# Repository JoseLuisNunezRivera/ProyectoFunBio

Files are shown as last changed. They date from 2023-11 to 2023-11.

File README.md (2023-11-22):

# Proyecto Fundamentos de Biodiseño: BIONOVA
**<p align="center">
¡Bienvenidos al repositorio del grupo 10 de Fundamentos de Biodiseño!**
</p>

# Conoce a nuestro equipo

<p align="center"> 
 
| Cargo | Apellidos y nombres | Imagen | GitHub |
|---|---| - | - |
| Coordinadora General | Micaela de Fátima Tassara Camarena |  | https://github.com/MDFTC |
| Coordinador de Modelado 3D | Jose Luis Jesús Nuñez Rivera | | https://github.com/JoseLuisNunezRivera | https://github.com/JoseLuisNunezRivera |
| Coordinador de Electrónica | Edgar Antonio Aguilar Ocas| | https://github.com/EdgarAguilar1 |
| Coordinadora de Programación | Andree Pascale Merino Contreras | | https://github.com/PascaleMerino |
| Coordinadora de Impresión 3D | Valeria Alejandra Leonardo Castillón | | https://github.com/ValeriaLeonardo |

</p>

# ¿A qué nos referimos con Open Science Hardware?
El Hardware es una parte esencial de procesos experimentales y los avances en la instrumentación han sido clave para revoluciones científicas. Sin embargo, la actual cadena de suministros de estos hardware científicos limita el acceso e impide la creatividad y personalización. El Open Science Hardware aborda esta problemática facilitando un espacio para compartir, diseñar y fabricar de manera abierta y accesible herramientas, dispositivos y equipos usados en investigaciones científicas y experimentos. Con esto se busca incrementar la transparencia, colaboración y accesibilidad en la comunidad científica, permitiendo que todo esto esté disponible gratuitamente a cualquiera para reproducir, modificar y compartir. [14]

# I. Analisis del caso 
- "Tema": Open Science Hardware para Salud y Laboratorio
- "Problemática": Aumento de quemaduras de segundo grado en menores de edad del país
 
### Contexto social
- Las quemaduras representan un desafío de salud pública a nivel global. No solo por la frecuencia y facilidad con la que ocurren, sino que, en función de su gravedad, pueden generar discapacidades e incluso la muerte. Según la OMS, a nivel mundial, se estima que alrededor de 180,000 muertes ocurren anualmente debido a quemaduras. En países con desarrollo medio y bajo, las quemaduras ocupan el tercer lugar como causa de muerte accidental. [1]
- En el Perú, “entre enero y febrero del 2023, el Instituto Nacional de Salud del Niño San Borja, recibió a 75 niños con quemaduras graves, cifra que se ha incrementado en 60% en relación al mismo periodo del 2022 que atendió a 47 menores de Lima y de las diversas regiones del país” [10].
- La recuperación de una persona quemada suele llevar semanas o incluso meses, durante los cuales experimenta dolor y sufrimiento tanto físico como emocional. El tratamiento y cuidado implica costos significativos, lo que genera tanto carga para el Estado como para la familia del afectado.(Martín y Piris, 2014). La morbilidad y mortalidad aumentan por la presencia de infección y por las heridas profundas que se presentan por la pérdida de la humedad de los tejidos expuestos por la quemadura. [2]
- Por otro lado, según los diagnósticos consignados en la base de datos de HIS, se puede identificar que las localizaciones más frecuentes de quemaduras son los extremos distales de los miembros (muñecas, manos, tobillos y pies), seguida de los miembros inferiores, cabeza - cuello. [3]

### Contexto económico
Uno de los tratamientos para quemaduras de segundo o tercer grado son los injertos de piel; sin embargo, este procedimiento médico es complejo puesto que se extrae piel sana para poder ser injertada en la zona quemada. Esto requiere un equipo especializado y recursos médicos no precarios, lo que significa un costo adicional. 
Según el Instituto Nacional de Salud del Niño, en la siguiente tabla se muestran los costos que un paciente puede asumir. 
**<p align="center"> **

Los costos pueden variar mucho según la región, el sistema de salud, el tipo de tratamiento requerido y otros factores.
### Definición del problema: 
Las quemaduras son lesiones producidas en tejido vivo, debido a la acción de agentes químicos o físicos, que provocan alteraciones que van desde un simple eritema transitorio hasta la destrucción total de las estructuras(4). 
La falta de tecnología de bioimpresión en Perú para el tratamiento de heridas por quemaduras representa una problemática grave en la atención médica. A medida que las quemaduras continúan siendo un problema de salud significativo en el país, la ausencia de esta tecnología avanzada limita las opciones de tratamiento efectivas y la posibilidad de una recuperación más rápida y completa para los pacientes. Esto se traduce en un aumento en la morbilidad y la carga económica en el sistema de salud peruano, así como en la calidad de vida disminuida para las personas afectadas por quemaduras. La falta de acceso a la bioimpresión también restringe la capacidad de la comunidad médica peruana para llevar a cabo investigaciones y avances en el campo de la regeneración de tejidos y la medicina regenerativa, lo que podría tener un impacto duradero en la atención médica en el país.
**<p align="center"> **

# II. Estado del arte 

## Productos comerciales
| Nombre | Características | Imágenes |
| --- | --- | --- |
| Biopen | El sistema Biopen incluye un sistema de extrusión motorizado, un cartucho de biotinta, una boquilla y una unidad de fotocurado. Con su unidad de luz visible reemplazable, permite reticular hidrogeles con diferentes fotoiniciadores. Con su sistema de extrusión ajustable, puede realizar bioimpresiones compatibles con las células y permite que el hidrogel cargado de células se imprima a la velocidad deseada en el cartucho. Fuente de fotocurado: LED de luz visible. Peso: 700 g. Velocidad de extrusión: 5 - 35 mm/min | WhatsApp Image 2023-09-12 at 23 39 20|
| AxceldaPen | Impresión de células óseas para tratar el desgaste de rodilla y daño al cartílago. Su bio tinta es a base de las propias células del paciente que son cultivadas previas a su cirugía, este proceso permite al cirujano medir el tamaño del cartílago necesario para cada paciente. | WhatsApp Image 2023-09-12 at 23 40 32 |
| iFixPen® | El iFixPen es un dispositivo de mano que entrega una estructura impresa en 3D directamente sobre defectos corneales. Entrega una estructura impresa en 3D directamente sobre defectos corneales. La tinta iFixInk, pendiente de patente, crea una estructura completamente transparente y biodegradable para sellar la herida, prevenir la infiltración de patógenos, aliviar el dolor y acelerar la curación. | WhatsApp Image 2023-09-12 at 23 41 24 |

## Patentes de invención y/o utilidad
### 1. CN110769771B: ROBOT IMPRESORA BIOLÓGICA TRIDIMENSIONAL. [15]
- Un sistema mínimamente invasivo que utiliza un robot quirúrgico como impresora tridimensional para fabricar tejido biológico en un sujeto. La planificación preoperatoria se utiliza para instruir y controlar el movimiento del robot y la extrusión robótica de biotinta. El movimiento del robot se coordina con la extrusión de tinta para formar capas del espesor y tamaño deseados, y el uso de diferentes tipos de tinta permite colocar el elemento compuesto. Dichos sistemas tienen un mecanismo de expulsión de biotinta de pequeño diámetro, generalmente en forma de cánula impulsada por un pistón, que permite el acceso a áreas con espacio limitado (como las articulaciones). El control robótico está programado para realizar un movimiento angular alrededor de un punto de pivote en un punto de inserción en el sujeto. La biotinta se puede almacenar en una capa predeterminada en la cánula para permitir la dispensación secuencial desde una cánula. Patente presentada en 2018, China.
La patente habla de un mecanismo de expulsión de biotinta de pequeño diámetro, en forma de cánula impulsada por un pistón, que utiliza un robot quirúrgico mientras que el prototipo pensado en el proyecto usa un “lápiz de impresión desmontable.” Estos son tipos de dispositivos de impresión diferentes.

<p align="center">
  
</p>

### 2. US11325301B2: EQUIPO DE IMPRESIÓN 3D QUE UTILIZA MATERIAL BIOLÓGICO Y SU MÉTODO. [16]
- Aparato de bioimpresión 3D y un método de bioimpresión tridimensional que utiliza el aparato. El aparato de bioimpresión 3D comprende un marco de impresora. Un dispositivo de lápiz de bioimpresión 3D está dispuesto en el marco de la impresora e incluye un lápiz de impresión desmontable. Patente presentada en 2017, Estados Unidos.

<p align="center">
  
</p>

### 3. US20200123485A1: DISPOSITIVOS, SISTEMAS Y MÉTODOS DE BIOIMPRESIÓN PARA IMPRIMIR GELES BLANDOS PARA EL TRATAMIENTO DE TRASTORNOS MUSCULOESQUELÉTICOS Y DE LA PIEL.[17]
- Dispositivos, sistemas y métodos que utilizan bioimpresoras para formar estructuras de andamio in situ para facilitar el tratamiento de trastornos musculoesqueléticos o de la piel en pacientes. Un método para tratar un trastorno musculoesquelético de un paciente incluye colocar una bioimpresora en un lugar del trastorno musculoesquelético, o en un lugar de una lesión cutánea, en el paciente. El método incluye extruir una formulación de hidrogel desde la bioimpresora al lugar. El método incluye curar la formulación de hidrogel en el lugar. La formulación de hidrogel tiene una composición eficaz para generar, tras el curado, una estructura de soporte en el lugar para facilitar la hipertrofia muscular o la curación de heridas de la piel en el lugar. Patente presentada en 2019, Estados Unidos.

<p align="center">
  
</p>

## Productos Open Hardware relacionados
### **1. An open-source handheld extruder loaded with pore-forming bioink for in situ wound dressing**

<p align="center">
  
</p>

#### Características:
- La jeringa es de 5mL
- Posee un regulador de velocidad. Esto para ajustarse a los requerimientos de la biotinta. Existe un potenciometro que permite el cambio de la velocidad de rotación del motor que es traducido a movimientos lineales del émbolo de la jeringa. Existían dos modos de operación: el primero era una parte movible que podia viajar hacia delante y empujar el émbolo de la jeringa para extruir; y el segundo, podía retraerse a una velocidad más rápida para colocar una nueva jeringa.
- Biotinta de dos fases basada en la mezcla de GelMA y PEO
- Crosslinkg a través de UV LEDs. Había un control de apago/prendido de los LEDs
- Existe una etapa de cooling antes de insertar la jeringa con la biotinta al biopen.
- Precio de 121 dólares.

#### Recomendaciones:
 - No posee arreglo multimaterial. Este puede incorporarse a futuro para permitir apósito heterogéneo.
 - El arreglo UV LED puede ser reemplazada por otra forma de crosslinking para evitar cualquier fotodaño potencial a la piel.
  
### **2. Handheld instrument for wound-conformal delivery of skin precursor sheets improves healing in full-thickness burns**

<p align="center">
  
</p>

#### Características:
- Peso: 1.4 kg
- Dimensiones: 20cm x 11cm x 15cm
- Uso de biotinta basada en fibrina y crosslinking enzimático por medio de una solución de trombina. Están en dos jeringas separadas y son co-deliveradas a su respectiva velocidad.
- La rueda de silicona funciona para estabilizar el contacto entre el cabezal de impresión y el lugar de la herida y para disipar las fuerzas impartidas por el peso del instrumento y del usuario. Esta rueda es de silicona para incementar la friccion con la superficie de deposición. Se ejerce una presión en el substrato menos de 12kPa.

### **3. 3D bio-printer from an off-shelf 3D printer (Prusa). The bioprinter is used for constructing 3D scaffold from hydrogels**

<p align="center">
 
</p>

#### Características: 
- Se cambió el extrusor original de la I3 y la boquilla de cabeza caliente, por 2 bombas peristálticas impresas en FDM.
- Nozzle impreso utilizando la impresora DLP-LCD "Anycubic Photon S" y resina transparente PLA+.
- Las piezas impresas se lavaron con alcohol isopropílico (IPA) y se curaron después de la impresión con luz ultravioleta LED.
- El biomaterial compuesto usado es una mezcla en diferentes concentraciones de alginato y gelatin.
- El crosslinking se realiza mediante la adición de 300mM de cloruro de calcio.
- El cloruro de calcio se añadio a manera de "spray" sobre las películas de hidrogel.

# Lista de requerimientos
*Funcionales: ¿Qué es lo que el diseño debe hacer?*
- Controlar el proceso de extrusión de material a una velocidad constante
- Funcionar por largos periodos de tiempo sin necesidad de ser alimentado por una fuente externa
- Adaptarse a cada forma de quemadura de segundo grado
- Mantener una temperatura constante que permita la preservación de las células durante la aplicación
  
*No funcionales: ¿Cuáles son las propiedades del diseño?*
- Cumplir con estándares de seguridad médica y estar diseñado para minimizar riesgos de infección o reacciones adversas en el paciente.
- Ser asequible y accesible para hospitales y clínicas médicas
- Ser portátil  y capaz de ser transportado fácilmente
- Carcasa exterior ergonómico y antideslizante

# Propuesta de solución
Sistema In Situ de bioimpresión de scaffolds con extrusión por bomba peristáltica y crosslinking iónico para la estimulación de cicatrización y prevención de infecciones en heridas causadas por quemaduras.

## Aclaraciones 
### Sistema de extrusión
https://www.ncbi.nlm.nih.gov/pmc/articles/PMC6527863/

- El proceso extrusión para bioimpresión permite el 70 a 75% de células vivas para el implante, a comparación de la bioimpresión por láser que es menor a este porcentaje

### Crosslinking
https://www.nature.com/articles/s41598-017-05699-x

- Para el proceso de “photocuring” se ha demostrado que es necesario solo 10 segundos de exposición a o 700mW/cm2 of 365nm UV-A para mantener el 90% de células vivas, para Bioandamios Core/Shell GelMa/HAMa con rigidez de 200KPa. Sin embargo, nos hemos decidido por un crosslinking iónico con cloruro de calcio para el alginato que usaremos como biomaterial para mantener las ceélular vivas.

### Biomateriales para la bioimpresión
https://drive.google.com/file/d/1x9udr_g3XU39Y2daWFmOKxjno0pU2IlR/view
#### Polímeros Naturales
- Alginato: Se ha utilizado ampliamente en bioimpresión por extrusión debido a su facilidad de impresión, para formar estructuras 3D, su compatibilidad con un cross-linkin iónico,  junto con su absorbencia de agua y bajo costo. El alginato también tiene propiedades inmunomoduladoras que pueden ser útiles en el tratamiento de la inflamación y enfermedades autoinmunes. Las soluciones de alginato han demostrado compatibilidad con muchos tipos de células de diferentes tejidos, como huesos, músculos, cartílagos, piel, nervios y sangre. Por ello, se ha utilizado en la cicatrización de heridas, la administración de fármacos y la ingeniería de tejidos. Una de las deventajas del alginato es la falta de moléculas de adhesión en el alginato, o glicoproteínas transmembrana, lo que reduce significativamente la interacción entre las células y el alginato, limitando así las funciones celulares. Las propiedades de adhesión del alginato se pueden mejorar agregando otros biomateriales que tengan capacidades inherentes para la unión celular.
  
- Ácido hialurónico: juega un papel importante en la hidratación, lubricación y proliferación celular de los tejidos. El HA estimula una respuesta inflamatoria y tiene potencial antigénico, lo que permite su uso extensivo en clínicas como relleno dérmico para la cicatrización de heridas. El HA es soluble en agua y la solución resultante tiene una alta viscosidad y, como tal, a menudo se utiliza como material auxiliar para ajustar la viscosidad de otras soluciones de biomateriales en bioimpresión. Las propiedades físicas y biológicas sintonizables hacen del HA un material adecuado para la incorporación de células. 

#### Polímeros compuestos
- El alginato y ácido hialurónico tienen propiedades complementarias. El alginato no tiene buenas propiedad de adhsesión, mientras que el ácido hialurónico posee una alta viscosidad y por ello puede ser utilizado como material auxiliar para aumentar las propiedad físicas del alginato, lo que mejora en gran medida la eficacia del crosslinking y la estabilidad mecánica del scaffold. Ambos ya son utilizados en el tratamiento de heridas, gracias a sus propiedades antiinflamatorias y antigénicas. Además gracias al alto contenido de agua del ácido hialurónico, el scaffold impreso puede promover el crecimiento y la proliferación celular. Todo ello resulta muy beneficioso para el objetivo del proyecto.

#### Proporción para el crosslinking de alginato y ácido hialurónico con cloruro de calcio
- Ácido hialurónico y alginato: Se utiliza una proporción de ácido hialurónico a alginato en el rango de 1:1 a 2:1. La inclusión de ácido hialurónico puede ayudar a mejorar la hidratación y promover la regeneración de tejidos.

- Concentración de cloruro de calcio: Se utiliza una solución de cloruro de calcio al 2-4% en peso en agua, que es una concentración comúnmente empleada en procesos de crosslinking. Sin embargo, la concentración exacta puede variar según las necesidades del proyecto y las condiciones de bioimpresión.

- Es importante señalar que la proporción exacta y la concentración de cloruro de calcio se van optimizando a través de pruebas empíricas para adaptarse a las características específicas del scaffold  deseado y a las condiciones de la herida que se desea tratar.

# III. Caja negra y esquema de funciones. MatrizMorfológica y Tabla de Valoración
## Caja negra

- Etapa de abstracción de nuestro proyecto a prototipar.
15d8d4c7-4761-4de0-bc48-b51743688ad0

## Esquema de funciones

- Listado de funciones que definen nuestra propuesta de solución

Gráfico Circular Azul Presentación

| Fúnción | Descripción |
|---|---|
| Regulador de energía | Regular la energía eléctrica para repartirla a todo el sistema|
| Control | Será la base de control de las acciones que el sistema realice. |
| Dosificación | Se refiere a la técnica de bioimpresión a utilizar para la dosificación del biomaterial en la zona deseada. Esta ténica será la extrusión. |
| Crosslinking | Proceso en el cual el biomaterial extruido será crosslinkeado. |

## Matriz morfologica
Gráfico Circular Azul Presentación (1)
 
## Tabla de valoración
WhatsApp Image 2023-09-19 at 23 55 50

# IV. Bocetos del Concepto Seleccionado. Tablade Evaluación Técnica y Económica
## Boceto inicial


## Boceto seleccionado
Gráfico Circular Azul Presentación (4)

**<p align="center"> Tamaño ideal ergonómico**
**<p align="center"> **

## Tabla de valoración económica
Captura de pantalla 2023-10-15 144806



## Tabla de valoración técnica
Captura de pantalla 2023-10-15 144519



## Gráfica de valoración


# Conclusión
El proyecto ofrece una visión prometedora para abordar un problema crítico de salud pública en Perú mediante el uso de tecnologías de bioimpresión accesibles y avanzadas. Sin embargo, es esencial abordar cuidadosamente los desafíos técnicos y de diseño, así como promover la colaboración y la adopción de Open Science Hardware en la comunidad médica para lograr un impacto significativo en la atención de quemaduras. Por esto, La propuesta número tres fue la elegida gracias a su costo asequible y gran eficacia. La bomba peristáltica con motor DC permite un flujo constante, rápido y controlado del biomaterial; además, el atomizador elegido permite realizar un crosslinking eficaz. A pesar de sus características avanzadas, es una opción asequible y posee un interfaz intuitivo y ergonómico, que lo hace fácil de utilizar.

# V. Diseño Esquemático y Simulación Electrónica. Modelado 3D de los componentes por separado

## Diagrama o esquema electrónico


## Simulador tinkercad


## Modelado 3D: Versión final
-LINK DE ONSHAPE: https://cad.onshape.com/documents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
### Bomba perístaltica
- Ensamble:
https://cad.onshape.com/documents/8de709f3be1f92d7d78226ca/w/8e6769958107216e33e4351b/e/bba23d80d86a9d90e47a93d3
- Rotor 1:
https://cad.onshape.com/documents/a1a31141d0e6236a7a8afdac/w/a38b574b1cf93c56c39f0876/e/4d92b41509b52d3259ff299a
- Tapa:
https://cad.onshape.com/documents/9d56f009d577c4719fb07cd5/w/0346843f56588c642b615e98/e/cd1f48146883c8e709fffaa5
- Base:
https://cad.onshape.com/documents/86ff641e1319ed8ba230f65f/w/cf8a607ef3fba1517b963901/e/06f48710efe4c3a660979ad4

### Caja electrónica
- Ensamble:
https://cad.onshape.com/documents/f10d689c1a461becbf3da6f5/w/d52496f38d187220b270d7e6/e/a1f287fec601dff3414ab840

### Interior de caja electrónica
- Caja:
https://cad.onshape.com/documents/4b100c79305f743f9210cc99
- Tapa:
https://cad.onshape.com/documents/b5b6cd9f3914f8a5b41c4516/w/a7186eeed686556f54d90923/e/6d1ff2c9b6ad1027c2815acc
- Soporte del motor y la bomba:
https://cad.onshape.com/documents/4ab95d31b83763a74a7c5df6
- Case de la batería: https://cad.onshape.com/documents/b5b6cd9f3914f8a5b41c4516/w/a7186eeed686556f54d90923/e/6d1ff2c9b6ad1027c2815acc

### Exterior de la caja electrónica (recipientes):
- Tapa:
https://cad.onshape.com/documents/b5b6cd9f3914f8a5b41c4516/w/a7186eeed686556f54d90923/e/6d1ff2c9b6ad1027c2815acc
- Base:
https://cad.onshape.com/documents/7edb1b0121b29fa5961d8425
- Recipiente:
https://cad.onshape.com/documents/59dc83f669816341396c27d1

### Dispositivo-Biopen
- Ensamble: https://cad.onshape.com/documents/fa43f6983dc2657439441877/w/561d306e3e23246e6a2a8a79/e/8833a1298579d56897545524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
- Carcasa (las dos partes): https://cad.onshape.com/documents/72aee932b03bc8e04e3bccb8/w/c4a85064b6552d9ff44133d4/e/d55f808f442a5059bc340e5d
- Nozzle:
https://cad.onshape.com/documents/bd66374ec5ace9d58c473229
- Boquilla:
https://cad.onshape.com/documents/afae13b7620b6a5cce17955e
- Tapa:
https://cad.onshape.com/documents/999addb3a5d2f49afebef456/w/5627ec29d2b8c1834bd65853/e/5afc472ae359bef1bf89bb87
- Soporte Joystick:
https://cad.onshape.com/documents/095865effa3b667ba34cd493

## Parámetros de impresión
The better way to buy real estate

## Planos componentes
https://github.com/JoseLuisNunezRivera/ProyectoFunBio/tree/main/Componentes

## Aclaraciones Componentes
- Los compartimientos reciben el cartucho de bimaterial a usar, por lo que reponible.
- El movimiento de la bomba en ambos sentidos permite evitar el "clouding".
- El prototipo será contruido en PLA, lo adecuado para uso médico son materiales como ácero inoxidable para el caso de la boquilla, PVC tranparente en el caso del protector dela boquilla.

### Limpieza de los componentes
Es importante resaltar estos puntos para evitar la contaminación entre pacientes, ya que al tratar quemaduras lo que principalmente se quiere evitar con las infecciones. Por ello, después del lavado de los ocmponentes expuestos al paciente con el clásico lavo de agua purificada:
- Se recomienda una desinfección de alto nivel (DAN) para el partes como la boquilla, el interiro de los artuchos y todo componente expuesto directamente a la contaminación. Esto puede ser con ácido peracético (0.001-0.2) durante 10 a 15 minutos, lo que se utiliza para desinfectar un equipo de diálisis.
- La limpieza interna se recomienda el uso de una solución NaOH al 8% para zonas no cercanas al paciente como la carcasa.
- La para la perte externa se recomienda el uso de hipoclorito 5000 ppm.

# VI. Iteración 1 (Hardware - Software -Manufactura Digital). Diagrama de Flujo
## Hardware
https://github.com/JoseLuisNunezRivera/ProyectoFunBio/edit/main/Hardware/HardwareREADME.md

## Software
https://github.com/JoseLuisNunezRivera/ProyectoFunBio/blob/main/Software/SoftwareREADME.md

# VII. Reporte de pruebas, retos y limitaciones
<p align="center"> 

## Videos de prueba:
https://drive.google.com/drive/folders/1dNpvZ_3heZI8Mf5WiS9OIGKs_0XBnwm1?usp=sharing

## Tabla de retos y limitaciones
| Retos y limitaciones | Posibles soluciones |
|-|-|
| Mejorar el sistema de almacenamiento del biomaterial | Diseñar un sistema que permita el intercambio de cartuchos |
| Mejorar la alimentación ante una emergencia | Implementar una batería de emergencia |
| Determinar con la mayor exactitud la proporción de Alginato con HA y CaCl2 | Lo recomendable es realizar pruebas experimentales para evaluarse y llegar a un promedio |
| La manguera más pequeña conseguida posee problemas con el espacio designado en la bomba|Editar el modelo con las nuevas medidas de la manguera|
| Las mangueras pueden estar muy sueltas |Agregar "caminos" en la carcasa para guiar las mangueras|

# VIII. Integración Hardware - Software - Manufactura Digital

## Verficación de diseño - Sofware
TS

## Verficación de diseño - Hardware
TH

## Verficación de diseño - Modelado 3D
TrQ

# Presentación HITO 01
https://www.canva.com/design/DAFyIOSvqEU/xKgEkVsLvqRSR0-aUGSA_A/edit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
# Presentación HITO 02
https://www.canva.com/design/DAF0h--ITno/4O1IoZnptE_-SC9zV_8JRQ/edit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

# Bibliografía 
- Bioimpresión
1.	Bioimpresión 3D [Internet]. Hisour.com. HiSoUR Arte Cultura Historia; 2018 [citado el 16 de noviembre de 2023]. Disponible en: https://www.hisour.com/es/3d-bioprinting-40712/amp/	 
2.	Cidonio G, Glinka M, Dawson JI, Oreffo ROC. The cell in the ink: Improving biofabrication by printing stem cells for skeletal regenerative medicine. Biomaterials [Internet]. 2019 [citado el 16 de noviembre de 2023];209:10–24. Disponible en: http://dx.doi.org/10.1016/j.biomaterials.2019.04.009
3.	Bolgiani A, Hermida E. Biompresión 3D de piel. Cir plást ibero-latinoam [Internet]. 2020 [citado el 16 de noviembre de 2023];46:85–90. Disponible en: https://scielo.isciii.es/scielo.php?script=sci_arttext&pid=S0376-78922020000200014 	 
4.	MacAdam A, Chaudry E, McTiernan CD, Cortes D, Suuronen EJ, Alarcon EI. Development of in situ bioprinting: A mini review. Front Bioeng Biotechnol [Internet]. 2022 [citado el 16 de noviembre de 2023];10. Disponible en: https://pubmed.ncbi.nlm.nih.gov/35935512/	 
5.	Varkey M, Visscher DO, van Zuijlen PPM, Atala A, Yoo JJ. Skin bioprinting: the future of burn wound reconstruction? Burns Trauma [Internet]. 2019 [citado el 16 de noviembre de 2023];7. Disponible en: https://pubmed.ncbi.nlm.nih.gov/30805375/	 
6.	Duchi S, Onofrillo C, O’Connell CD, Blanchard R, Augustine C, Quigley AF, et al. Handheld Co-Axial Bioprinting: Application to in situ surgical cartilage repair. Sci Rep [Internet]. 2017 [citado el 16 de noviembre de 2023];7(1):1–12. Disponible en: https://www.nature.com/articles/s41598-017-05699-x

- Noticias
1.	BBC News Mundo. Anthony Atala, el científico peruano que busca un lugar en la historia de la medicina con una impresora. BBC [Internet]. el 17 de marzo de 2016 [citado el 16 de noviembre de 2023]; Disponible en: https://www.bbc.com/mundo/noticias/2016/03/160315_atala_impresora_organos_am 	 
2.	Com.au. [citado el 16 de noviembre de 2023]. Disponible en: https://mivision.com.au/2018/09/australian-ifix-pen-seals-corneal-wounds 	
3.	INSN SAN BORJA: CASOS DE NIÑOS QUEMADOS SE INCREMENTA EN 60% EN LO QUE VA DE ESTE AÑO 2023 [Internet]. Gob.pe. [citado el 16 de noviembre de 2023]. Disponible en: https://www.insnsb.gob.pe/blog/2023/03/10/insn-san-borja-casos-de-ninos-quemados-se-incrementa-en-60-en-lo-que-va-de-este-ano-2023/ 	 
4.	INSN SAN BORJA SALVA VIDA DE PACIENTES CON EXTENSAS QUEMADURAS CON APLICACIÓN DE PIEL CULTIVADA [Internet]. Gob.pe. [citado el 16 de noviembre de 2023]. Disponible en: https://www.insnsb.gob.pe/blog/2016/04/27/insn-san-borja-salva-vida-de-pacientes-con-extensas-quemaduras-con-aplicacion-de-piel-cultivada/
5.	Tejido humano en impresora 3D [Internet]. Expansi�n.com. 2017 [citado el 16 de noviembre de 2023]. Disponible en: https://www.expansion.com/economia-digital/innovacion/2017/07/31/5979fa8e268e3e774b8b45b2.html
 	 
- Hardware
1.	Why GOSH? [Internet]. Gathering for Open Science Hardware - Gathering for Open Science Hardware. Gathering for Open Science Hardware; 2016 [citado el 22 de noviembre de 2023]. Disponible en: https://openhardware.science/about/why-gosh/

- Productos comercializados
1.	Axcelda [Internet]. Axcelda.com. [citado el 22 de noviembre de 2023]. Disponible en: https://axcelda.com/
2.	BioPen-X (handheld bioprinter) [Internet]. Adbioink. [citado el 22 de noviembre de 2023]. Disponible en: https://www.adbioink.com/product/biopen-handheld-bioprinter/
 	 
- Patentes
1.	Espacenet [Internet]. Espacenet.com. [citado el 22 de noviembre de 2023]. Disponible en: https://worldwide.espacenet.com/patent/search/family/063712092/publication/CN110769771B?q=pn%3DCN110769771B	 
2.	Espacenet [Internet]. Espacenet.com. [citado el 22 de noviembre de 2023]. Disponible en: https://worldwide.espacenet.com/patent/search/family/056325304/publication/US11325301B2?q=pn%3DUS11325301B2 	 
3.	Espacenet [Internet]. Espacenet.com. [citado el 22 de noviembre de 2023]. Disponible en: https://worldwide.espacenet.com/patent/search/family/070279465/publication/US2020123485A1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

- Quemaduras
1.	Wound care after burn injury [Internet]. Msktc.org. [citado el 22 de noviembre de 2023]. Disponible en: https://msktc.org/burn/factsheets/wound-care-after-burn-injury 	 
2.	Quemaduras [Internet]. Who.int. [citado el 22 de noviembre de 2023]. Disponible en: https://www.who.int/es/news-room/fact-sheets/detail/burns 	 
3.	Vista de PIEL DE CERDO LIOFILIZADA EN TRATAMIENTO DE QUEMADURAS: SERIE DE CASOS 2014-2016 [Internet]. Edu.pe. [citado el 22 de noviembre de 2023]. Disponible en: https://revistas.uss.edu.pe/index.php/tzh/article/view/1329/1267	 
4.	Gob.pe. [citado el 22 de noviembre de 2023]. Disponible en: https://cdn.www.gob.pe/uploads/document/file/1400166/RM%20883-2020-MINSA.PDF.PDF 	 
5.	Tian H, Wang L, Xie W, Shen C, Guo G, Liu J, et al. Epidemiologic and clinical characteristics of severe burn patients: results of a retrospective multicenter study in China, 2011–2015. Burns Trauma [Internet]. 2018 [citado el 22 de noviembre de 2023];6. Disponible en: https://pubmed.ncbi.nlm.nih.gov/29850643/ 	 
6.	Peck MD. Epidemiology of burns throughout the world. Part I: Distribution and risk factors. Burns [Internet]. 2011;37(7):1087–100. Disponible en: https://www.sciencedirect.com/science/article/pii/S0305417911001914	 
7.	Chau Ramos EA, Hospital María Auxiliadora, Unidad de Cirugía Plástica. Lima, Perú. Evaluación de cicatrización en zonas donantes de injerto de piel parcial con uso de Xenoinjerto en comparación con sustituto dérmico. Horiz méd [Internet]. 2019 [citado el 22 de noviembre de 2023];19(3):20–6. Disponible en: https://www.horizontemedico.usmp.edu.pe/index.php/horizontemed/article/view/1070 	 
8.	Vista de Costos directos en el que incurre el Instituto Nacional de Salud del Niño en el tratamiento de niños quemados [Internet]. Edu.pe. [citado el 22 de noviembre de 2023]. Disponible en: https://revistas.unjfsc.edu.pe/index.php/INFINITUM/article/view/340/329
 	 
- Bioimpresoras
1.	Ink D. Open & affordable 3D bioprinting [Internet]. Hackster.io. [citado el 22 de noviembre de 2023]. Disponible en: https://www.hackster.io/dynamic-ink/open-affordable-3d-bioprinting-14d68b 	 
2.	Pazhouhnia Z, Beheshtizadeh N, Namini MS, Lotfibakhshaiesh N. Portable hand‐held bioprinters promote in situ tissue regeneration. Bioeng Transl Med [Internet]. 2022;7(3). Disponible en: http://dx.doi.org/10.1002/btm2.10307 
3.	Ahmed_EGomaa, grad. DIY 3D bio-printer [Internet]. Hackster.io. [citado el 22 de noviembre de 2023]. Disponible en: https://www.hackster.io/473403/diy-3d-bio-printer-9ecea6 
4.	de Grado TF. Departamento de Sistemas y Automática Grado en Ingeniería Electrónica Industrial y Automática [Internet]. Uc3m.es. [citado el 22 de noviembre de 2023]. Disponible en: https://e-archivo.uc3m.es/bitstream/handle/10016/16853/TFG_Marco_Esteban_Illescas.pdf?sequence=1&isAllowed=y	 
5.	[citado el 22 de noviembre de 2023]. Disponible en: http://file:///C:/Users/mftas/Downloads/IJB-7-2-337.pdf
 	 
- Limpieza de componentes
1.	Matsos S. Bioprinting experiment preparation in 8 easy steps [Internet]. Allevi. 2020 [citado el 22 de noviembre de 2023]. Disponible en: https://www.allevi3d.com/preparing-for-a-biostudy/
2.	Sas FC. Ácido Peracético, nueva tecnología de fabricación que disminuye corrosión en acero inoxidable [Internet]. Flow Chem - Productos de Limpieza y Desinfección. Flow Chem SAS; 2019 [citado el 22 de noviembre de 2023]. Disponible en: https://www.flowchem.com.co/corrosion-desinfectante-acido-peracetico/	 
3.	Hernández-Navarrete M-J, Celorrio-Pascual J-M, Lapresta Moros C, Solano Bernad V-M. Fundamentos de antisepsia, desinfección y esterilización. Enferm Infecc Microbiol Clin [Internet]. 2014 [citado el 22 de noviembre de 2023];32(10):681–8. Disponible en: https://www.elsevier.es/en-revista-enfermedades-infecciosas-microbiologia-clinica-28-articulo-fundamentos-antisepsia-desinfeccion-esterilizacion-S0213005X14001839 	 
4.	Natalia L, Rodríguez C. LAVADO Y DESINFECCION DE MATERIAL LABORATORIO CLINICO [Internet]. Gov.co. [citado el 22 de noviembre de 2023]. Disponible en: https://www.cribsaludmental.gov.co/attachments/category/425/M-AD-LC-M01%20MANUAL%20LAVADO%20Y%20DESINFECCION%20DE%20MATERIAL%20LABORATORIO%20CLINICO.pdf 	 
5.	Sochihem.cl. [citado el 22 de noviembre de 2023]. Disponible en: https://www.sochihem.cl/bases/arch1202.pdf 	 
6.	Santolaria S, Ducons J, Maria Bordas J. Limpieza y desinfección en endoscopia digestiva. Gastroenterol Hepatol [Internet]. 2007 [citado el 22 de noviembre de 2023];30(1):25–35. Disponible en: https://www.elsevier.es/es-revista-gastroenterologia-hepatologia-14-articulo-limpieza-desinfeccion-endoscopia-digestiva-13097448	 
7.	Gargallo CJ, Ferrandez A, Carrera P, Simon MA, Ducons J, Lanas A. Short- and long-term clinical outcomes of self-expandable metal stents inserted for colorectal obstruction and efficacy of different insertion techniques. Gastroenterol Hepatol [Internet]. 2019 [citado el 22 de noviembre de 2023];42(3):157–63. Disponible en: https://www.elsevier.es/es-revista-gastroenterologia-hepatologia-14-articulo-short-long-term-clinical-outcomes-self-expandable-S0210570518302449 	 
8.	Marketing Simmedica-PENTAX. Desinfección de endoscopios Paso a Paso [Internet]. Simmedica.com. PENTAX Medical Iberia SAU; 2021 [citado el 22 de noviembre de 2023]. Disponible en: https://blog.simmedica.com/blog/desinfeccion-de-endoscopios-paso-a-paso 	 
9.	Logic Clean. Desinfección y Esterilización con Luz Ultravioleta • [Internet]. LogicClean. 2017 [citado el 22 de noviembre de 2023]. Disponible en: https://logicclean.es/la-desinfeccion-esterilizacion-luz-ultravioleta/

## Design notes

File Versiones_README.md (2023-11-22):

- En esta sección hemos colocados bocetos y versiones dle modelado pasados que fueron descartados en el camino a medida que ibamos llegando a nuestra idea final

# Bocetos
## Boceto 1 (Modificado)
-La idea principal de este boceto, era acomodar todos los componentes dentro del dispositivo, pero el es acio era reducido si queríamos mantener un diseño ergonómico, además de nivelar el peso. Asimismo, la idea inicial era con botones, en lugar deun Joystick.



- Por lo que se decidió, agregarle un mango para hacer más manejable el peso y así aumentar el espacio. Sin embargo, eso afectaba el movimiento de la mano al momento de "dibujar", por ello este boceto paso por otros cambios.

b5

-Finalmente, llegamos la boceto que se acercaba más a nuestra meta.
Gráfico Circular Azul Presentación (4)

## Boceto 2
b6

## Boceto 3 
b7

- El boceto seleccionado fue el boceto 1, por lo que durante el proceso demodelado fue cambiando hasta el boceto final.

# Versiones del modelado 3D
## Versión I
-Siguiendo el primer boceto, la primera limitación: Limitación del campo dvisión alrrededor de la boquilla, además del mango qulimitaba más el movimiento de la mano.



### Modelado de los componentes
| Componente | Imagen | Plano | Impresión |
|---|---|---|---|
|Carcasa de batería: https://skfb.ly/oMzyD|  | Bateria |  |
| Soporte Arduino Nano IoT: https://skfb.ly/oMyWH |  | arduino | carcasa arduino y carcasa abteria |
| Soporte bomba: https://skfb.ly/oMzPo |  | - | sopprte motores |
| Nozzle: https://skfb.ly/oMKX9 |  | Nozzle | - | noozle |

## Versión II
-Decidimos volver a la idea del "lápiz", pero que el material sea transparente.


Enlace: https://cad.onshape.com/documents/ea4d05391d26cad5344d7bf4/w/5630425b4178665594f26478/e/341b976ba16a7e19a7a6a8cc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

### Parámetros de impresión
| Componente | Impresión |
|---|---|
| Bomba peristáltica |  |
| Nozzle |  |
| Soporte arduino y batería |  |
| Carcasa derecha e izquierda |  |
| Tapa y boquilla | 

## Versión III
- En el anterior modelado tuvimos los problemas quidentificamos al inicio: Los componentes adentro generan un desnivel de peso y el poco espacio dentro.



- Para solucionar esto decidimos generar una curvatura que sirva de apoyo en la parte de atrás de la mano, pero esto no generaba una grna diferencia



## Versión IV
- Esta es la última versión, la desición final fue tener los componentes electrónicos en una caja y el dipsoitivo d mano, es decir el BioPen que contenga solo el joystick y el nozzle, donde se conectaran las magueras con las biotintas desde la caja.

### Dispositivo de mano


### Caja electrónica


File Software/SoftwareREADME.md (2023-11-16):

# Diagrama de Flujo
Diagrama de flujo

# Código
https://github.com/JoseLuisNunezRivera/ProyectoFunBio/blob/main/Software/Codigo.ino

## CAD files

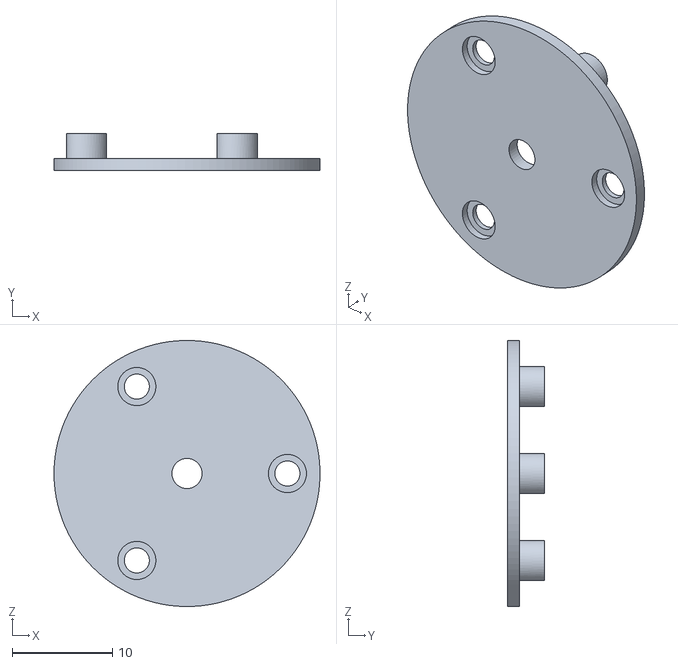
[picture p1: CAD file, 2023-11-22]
Componentes/STL. /Boma peristáltica/Rotor2 v6.stl
26.5 x 3.70 x 26.5

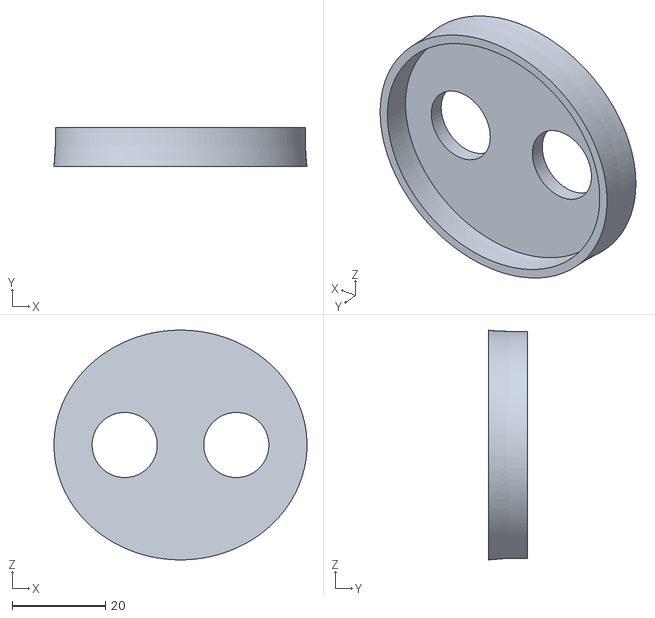
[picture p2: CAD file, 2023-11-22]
Componentes/STL./Tapa carcasa.stl
54.4 x 8.40 x 49.4

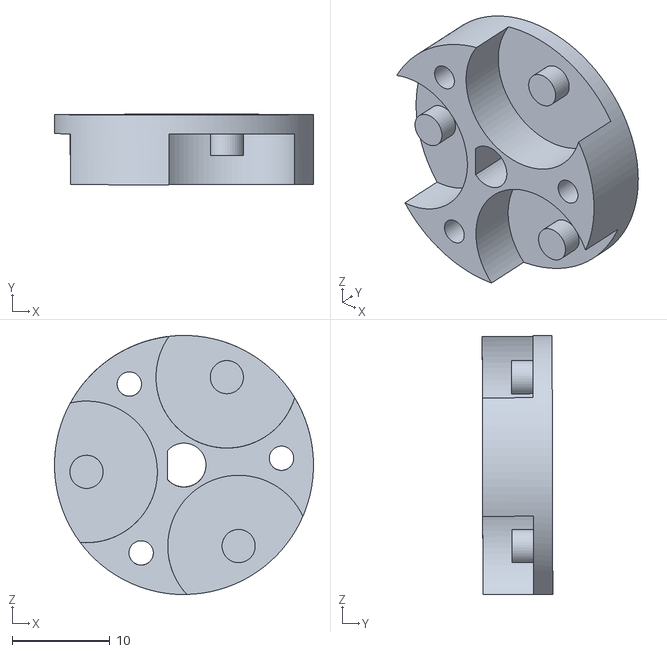
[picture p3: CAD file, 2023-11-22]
Componentes/STL. /Boma peristáltica/Rotor1 v8.stl
26.5 x 7.22 x 26.5

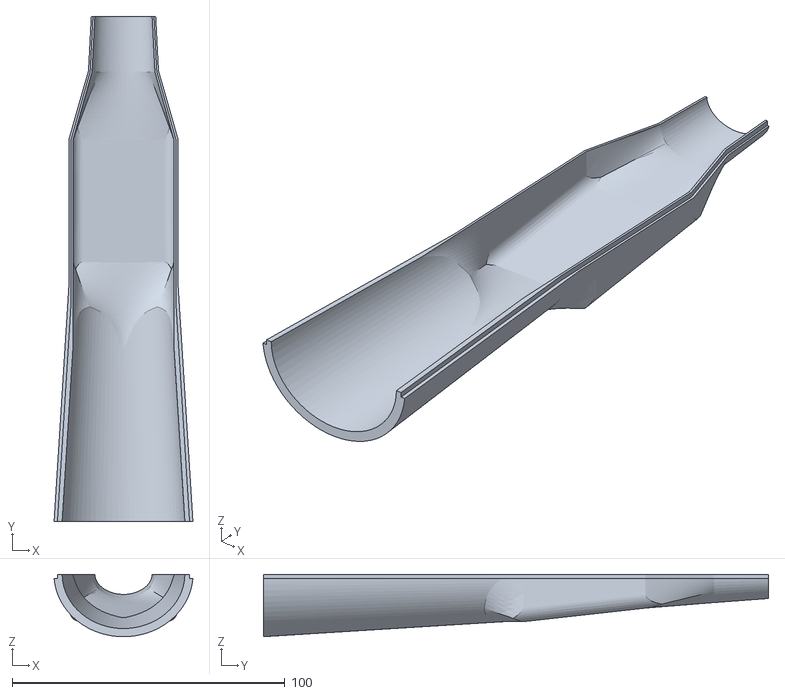
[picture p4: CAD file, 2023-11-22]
Componentes/STL./Carcasa parte 2.stl
50.9 x 185.0 x 22.9

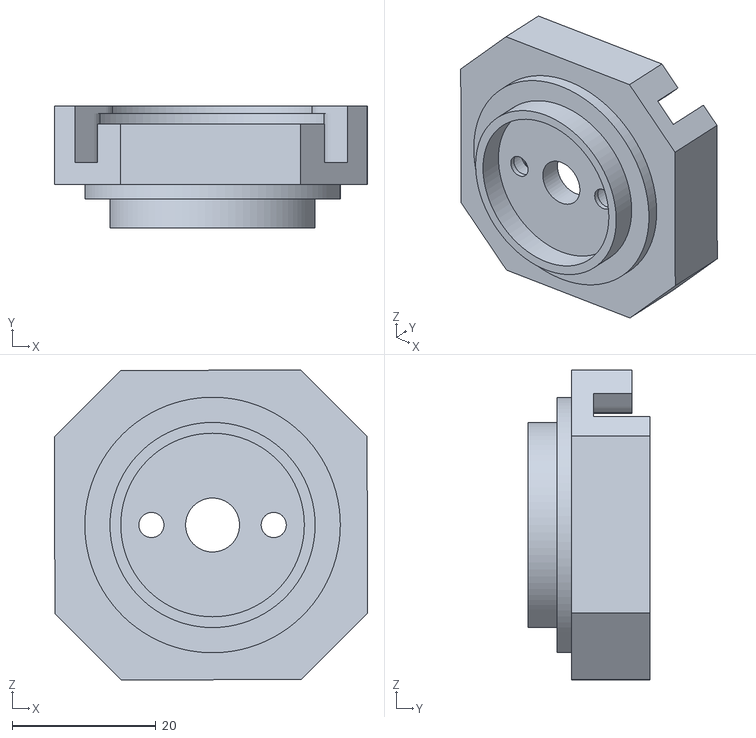
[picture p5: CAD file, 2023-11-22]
Componentes/STL. /Boma peristáltica/Base final final (3).stl
43.5 x 16.9 x 43.1

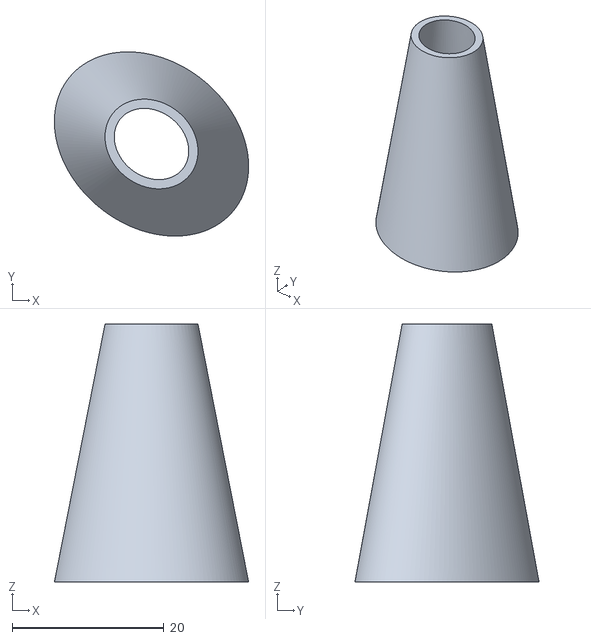
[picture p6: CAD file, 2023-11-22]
Componentes/STL./UMS5_Boquilla v1.stl
25.6 x 24.3 x 34.0

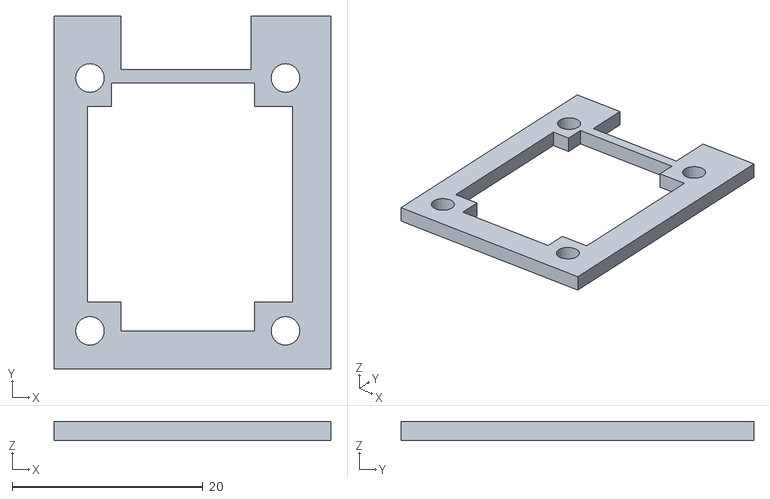
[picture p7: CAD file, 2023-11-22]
Componentes/STL./UMS5_Beta v20.stl
29.0 x 37.0 x 2.00

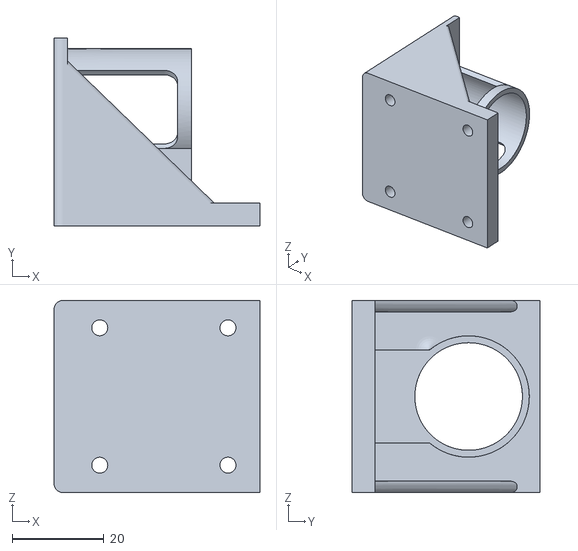
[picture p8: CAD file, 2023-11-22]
Componentes/STL./Soporte de motor v2 (1).stl
45.0 x 41.0 x 42.0

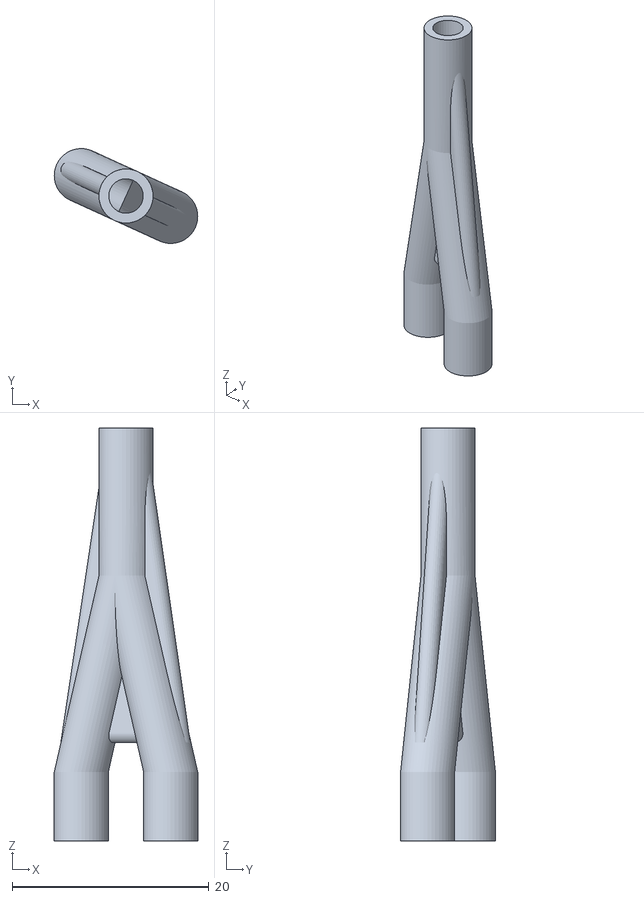
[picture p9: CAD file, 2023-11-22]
Componentes/STL./UMS5_NOZZLE v5.stl
14.6 x 9.65 x 42.0

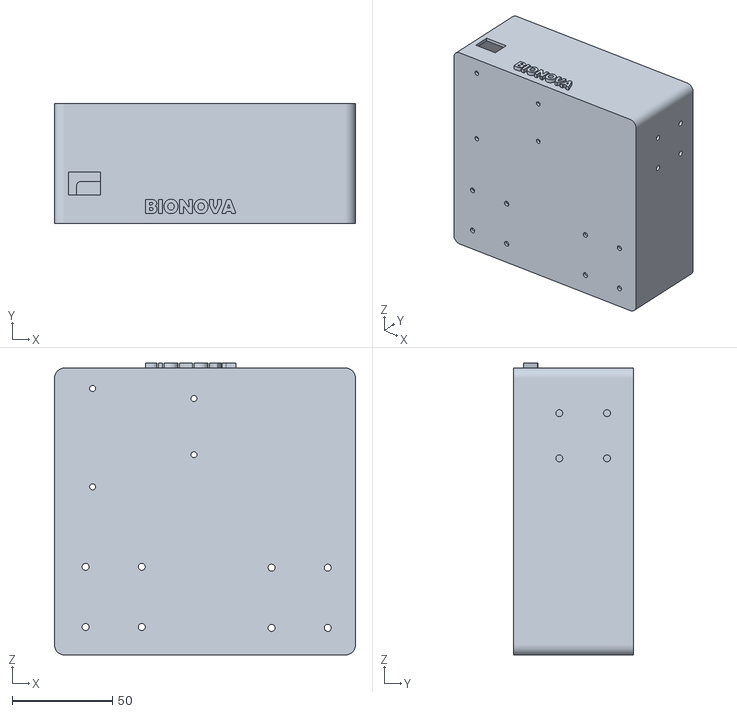
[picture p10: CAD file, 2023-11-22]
Componentes/STL./Caja componentes electrónicos.stl
150.0 x 60.0 x 145.5

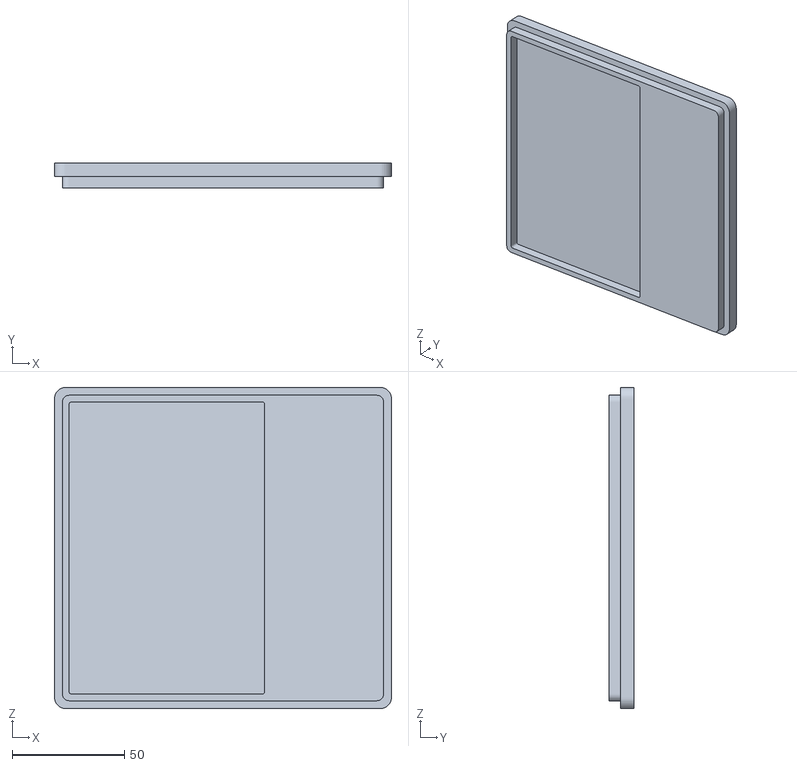
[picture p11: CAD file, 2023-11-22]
Componentes/STL./Tapa caja componentes electrónicos.stl
150.0 x 11.0 x 143.0

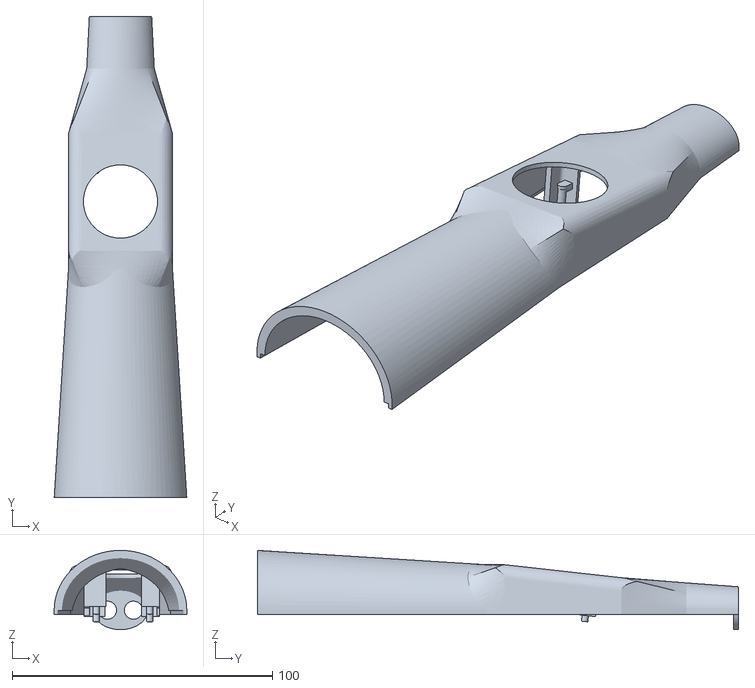
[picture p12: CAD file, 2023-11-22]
Componentes/STL./CARCASA v15.stl
51.0 x 185.0 x 30.5

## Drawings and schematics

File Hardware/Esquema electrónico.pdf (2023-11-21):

Fuente de alimentaci n | Pulsadores
Bateria 9v | bateria 9v

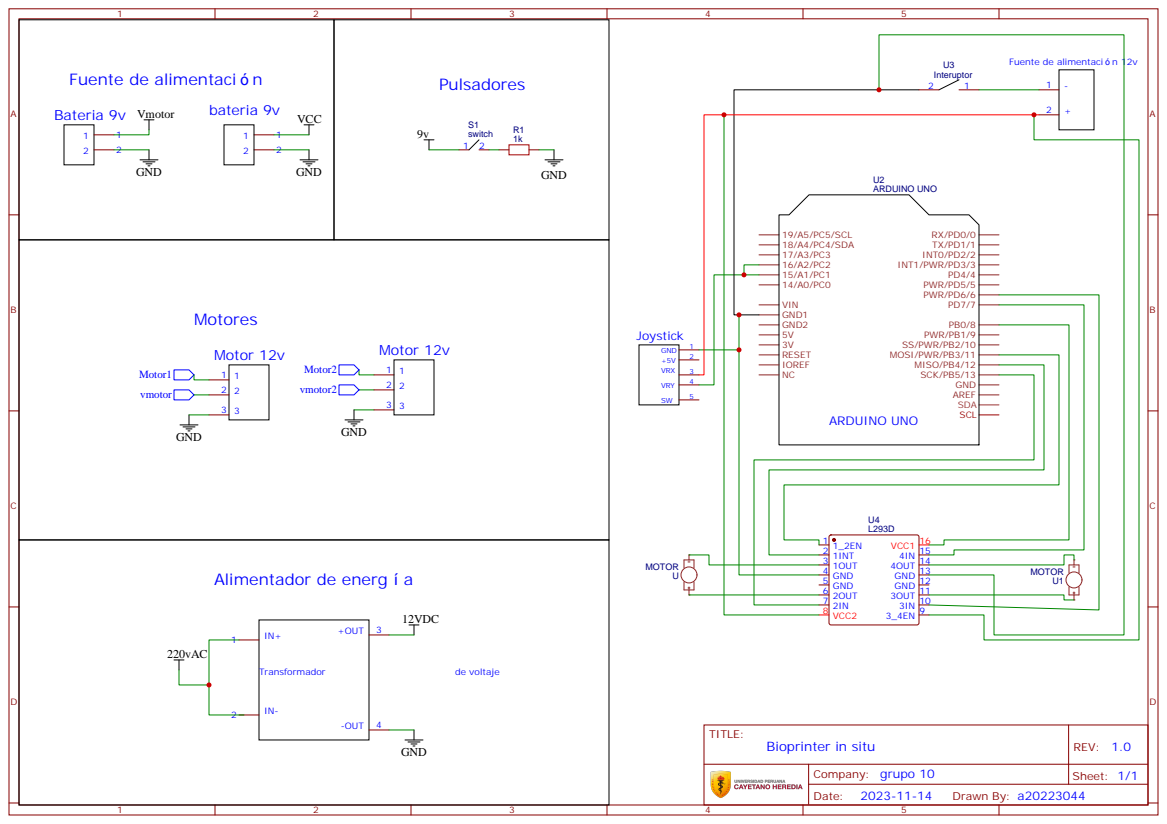
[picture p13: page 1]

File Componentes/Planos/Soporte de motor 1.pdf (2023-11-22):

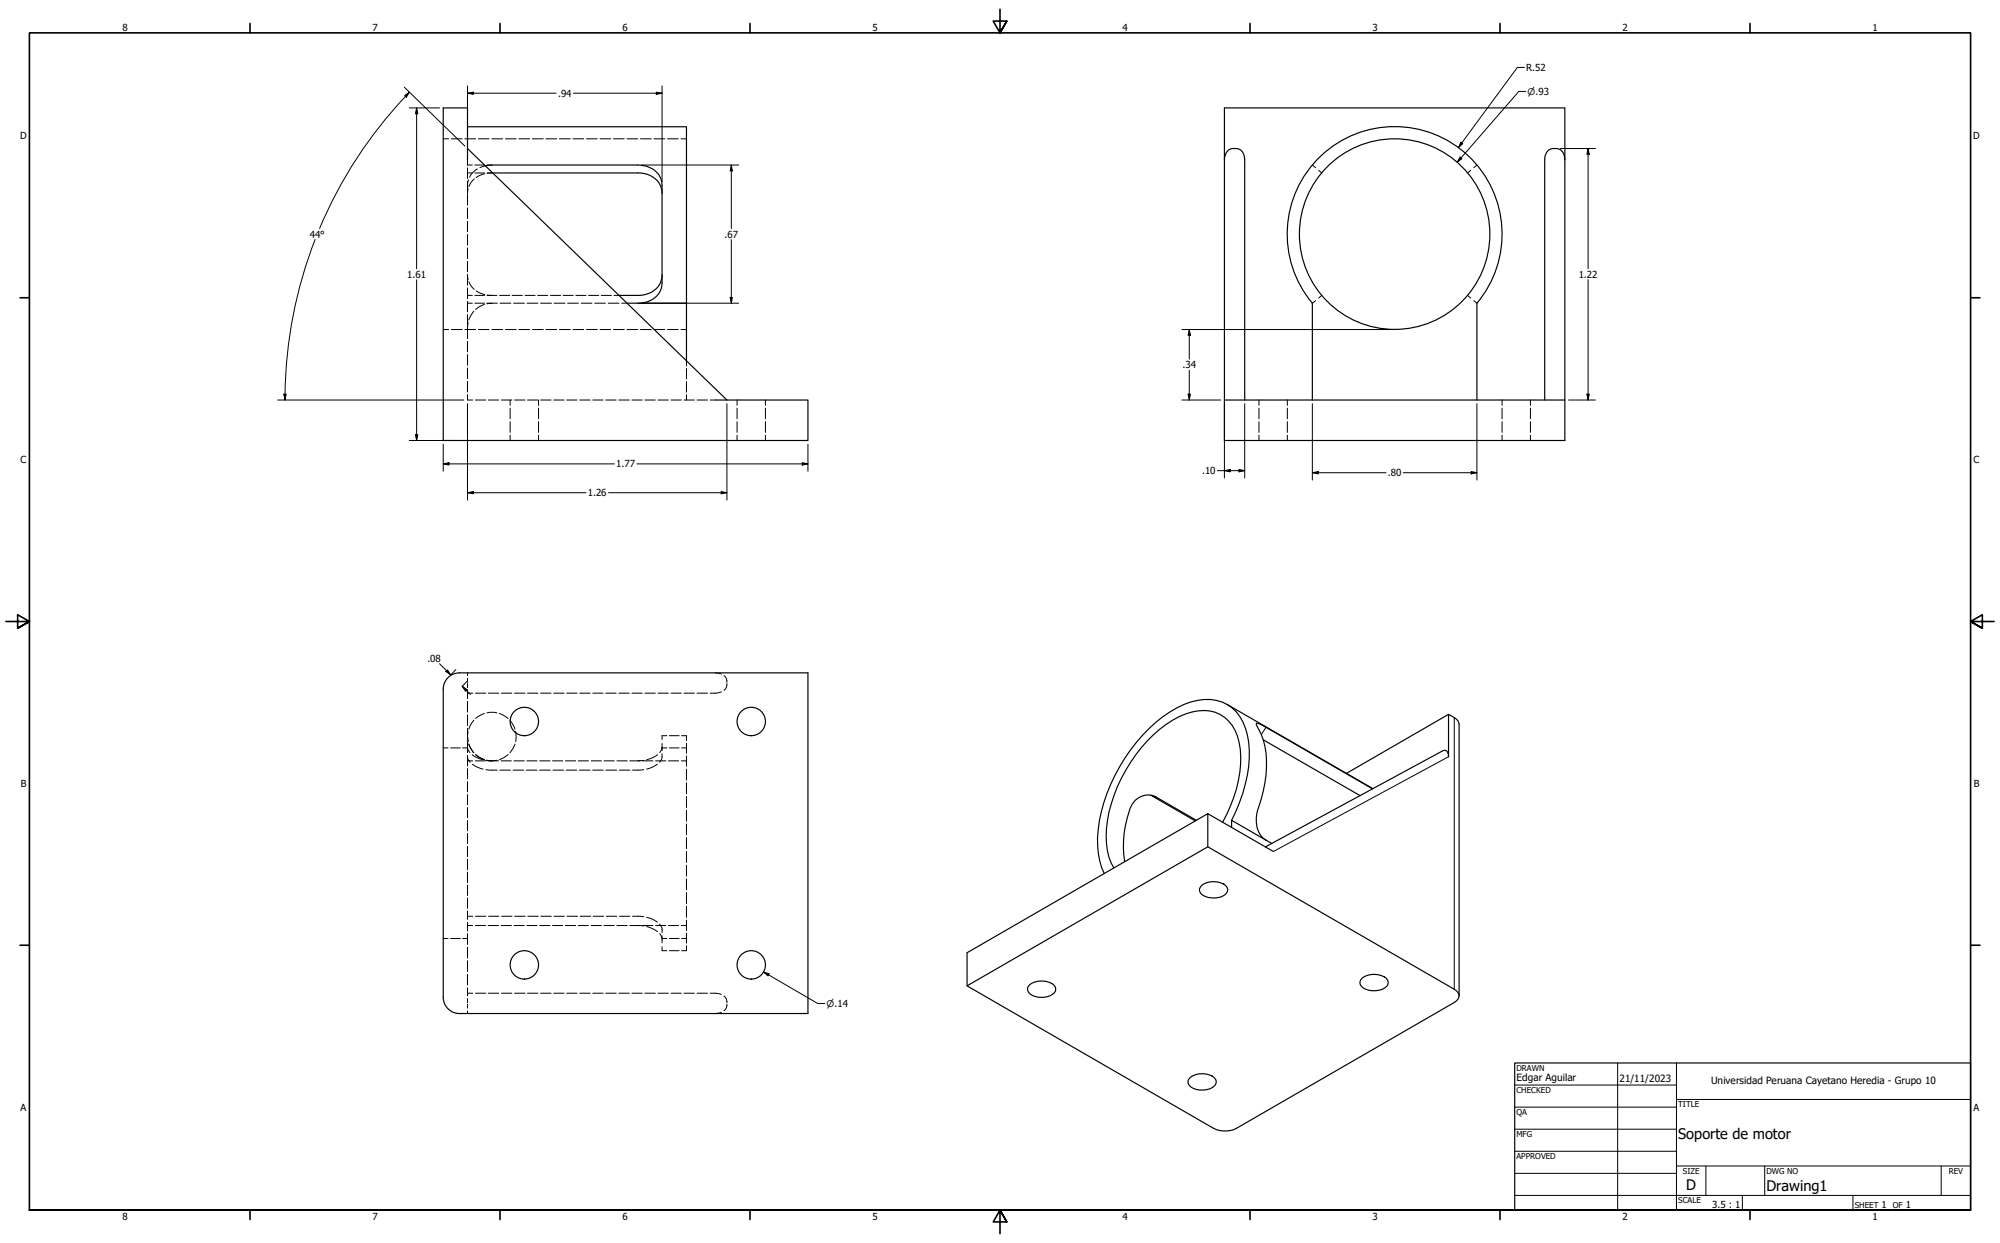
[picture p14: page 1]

DRAWN Edgar Aguilar | 21/11/2023 | Universidad Peruana Cayetano Heredia - Grupo 10

CHECKED

Soporte de motor

MFG

APPROVED

SIZE D | DWG NO Drawing1 | REV

SCALE 3.5 : 1 | | SHEET 1 OF 1

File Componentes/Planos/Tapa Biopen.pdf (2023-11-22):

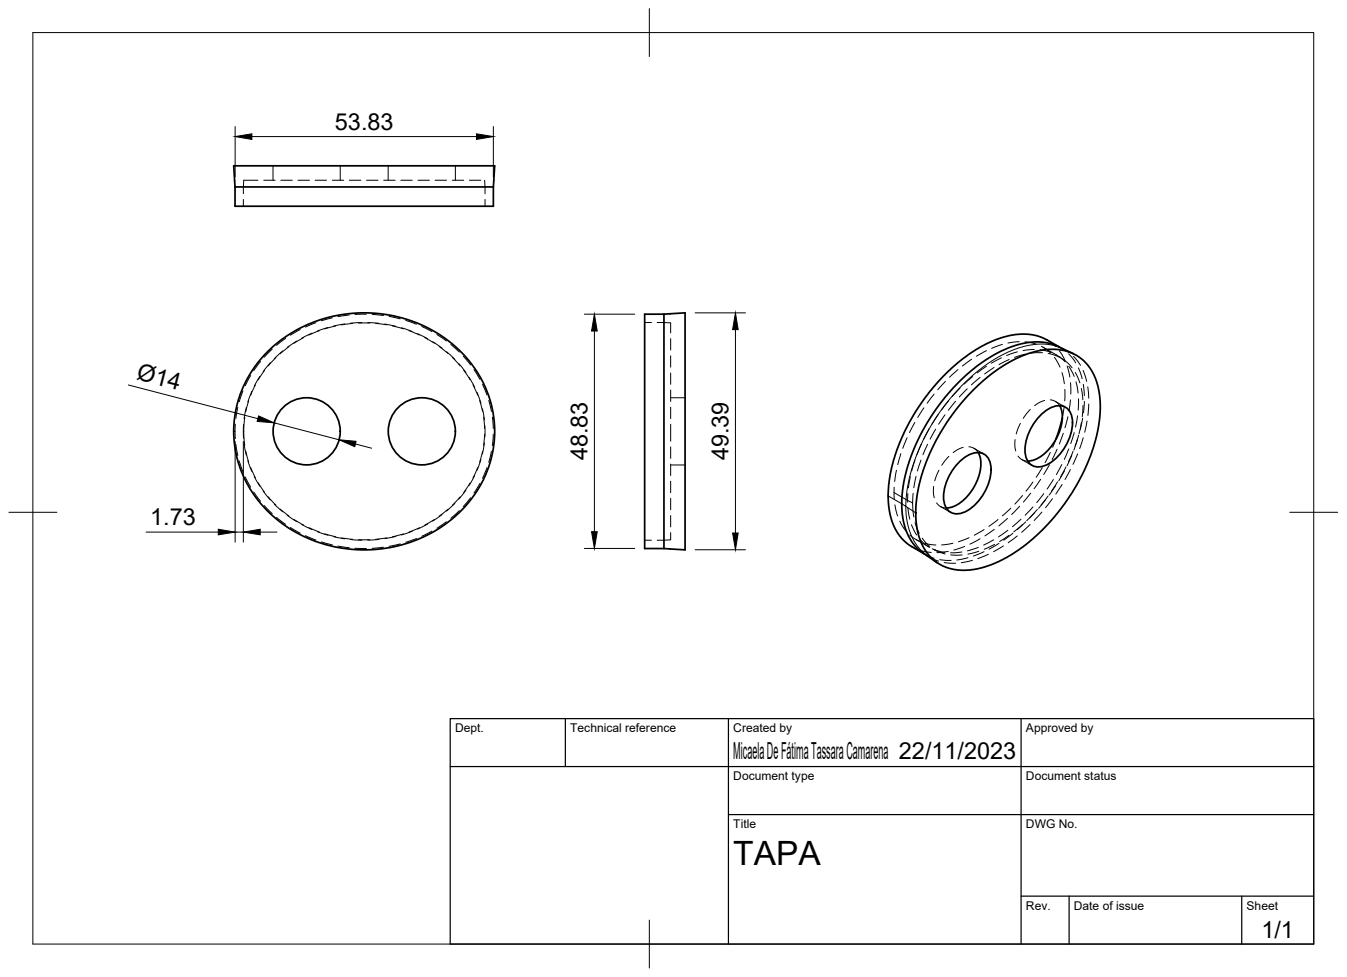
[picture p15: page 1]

Dept. | Technical reference | Created by Micaela De Fátima Tassara Camarena 22/11/2023 | Approved by

Document type | Document status

Title TAPA | DWG No.

Rev. | Date of issue | Sheet 1/1

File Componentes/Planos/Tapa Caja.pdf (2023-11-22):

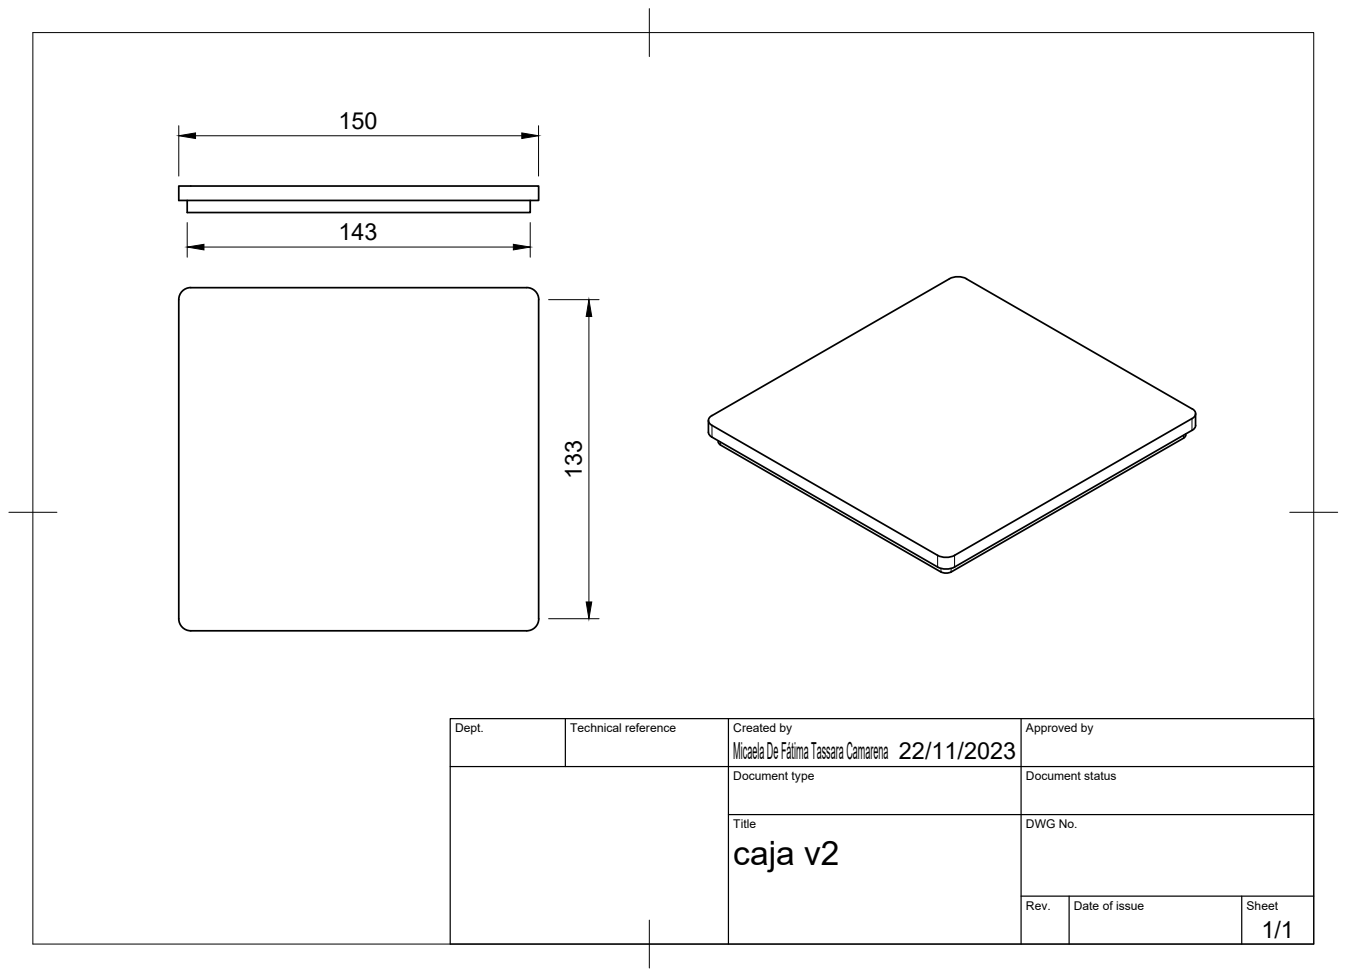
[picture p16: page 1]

Dept. | Technical reference | Created by Micaela De Fátima Tassara Camarena 22/11/2023 | Approved by

Document type | Document status

Title caja v2 | DWG No.

Rev. | Date of issue | Sheet 1/1

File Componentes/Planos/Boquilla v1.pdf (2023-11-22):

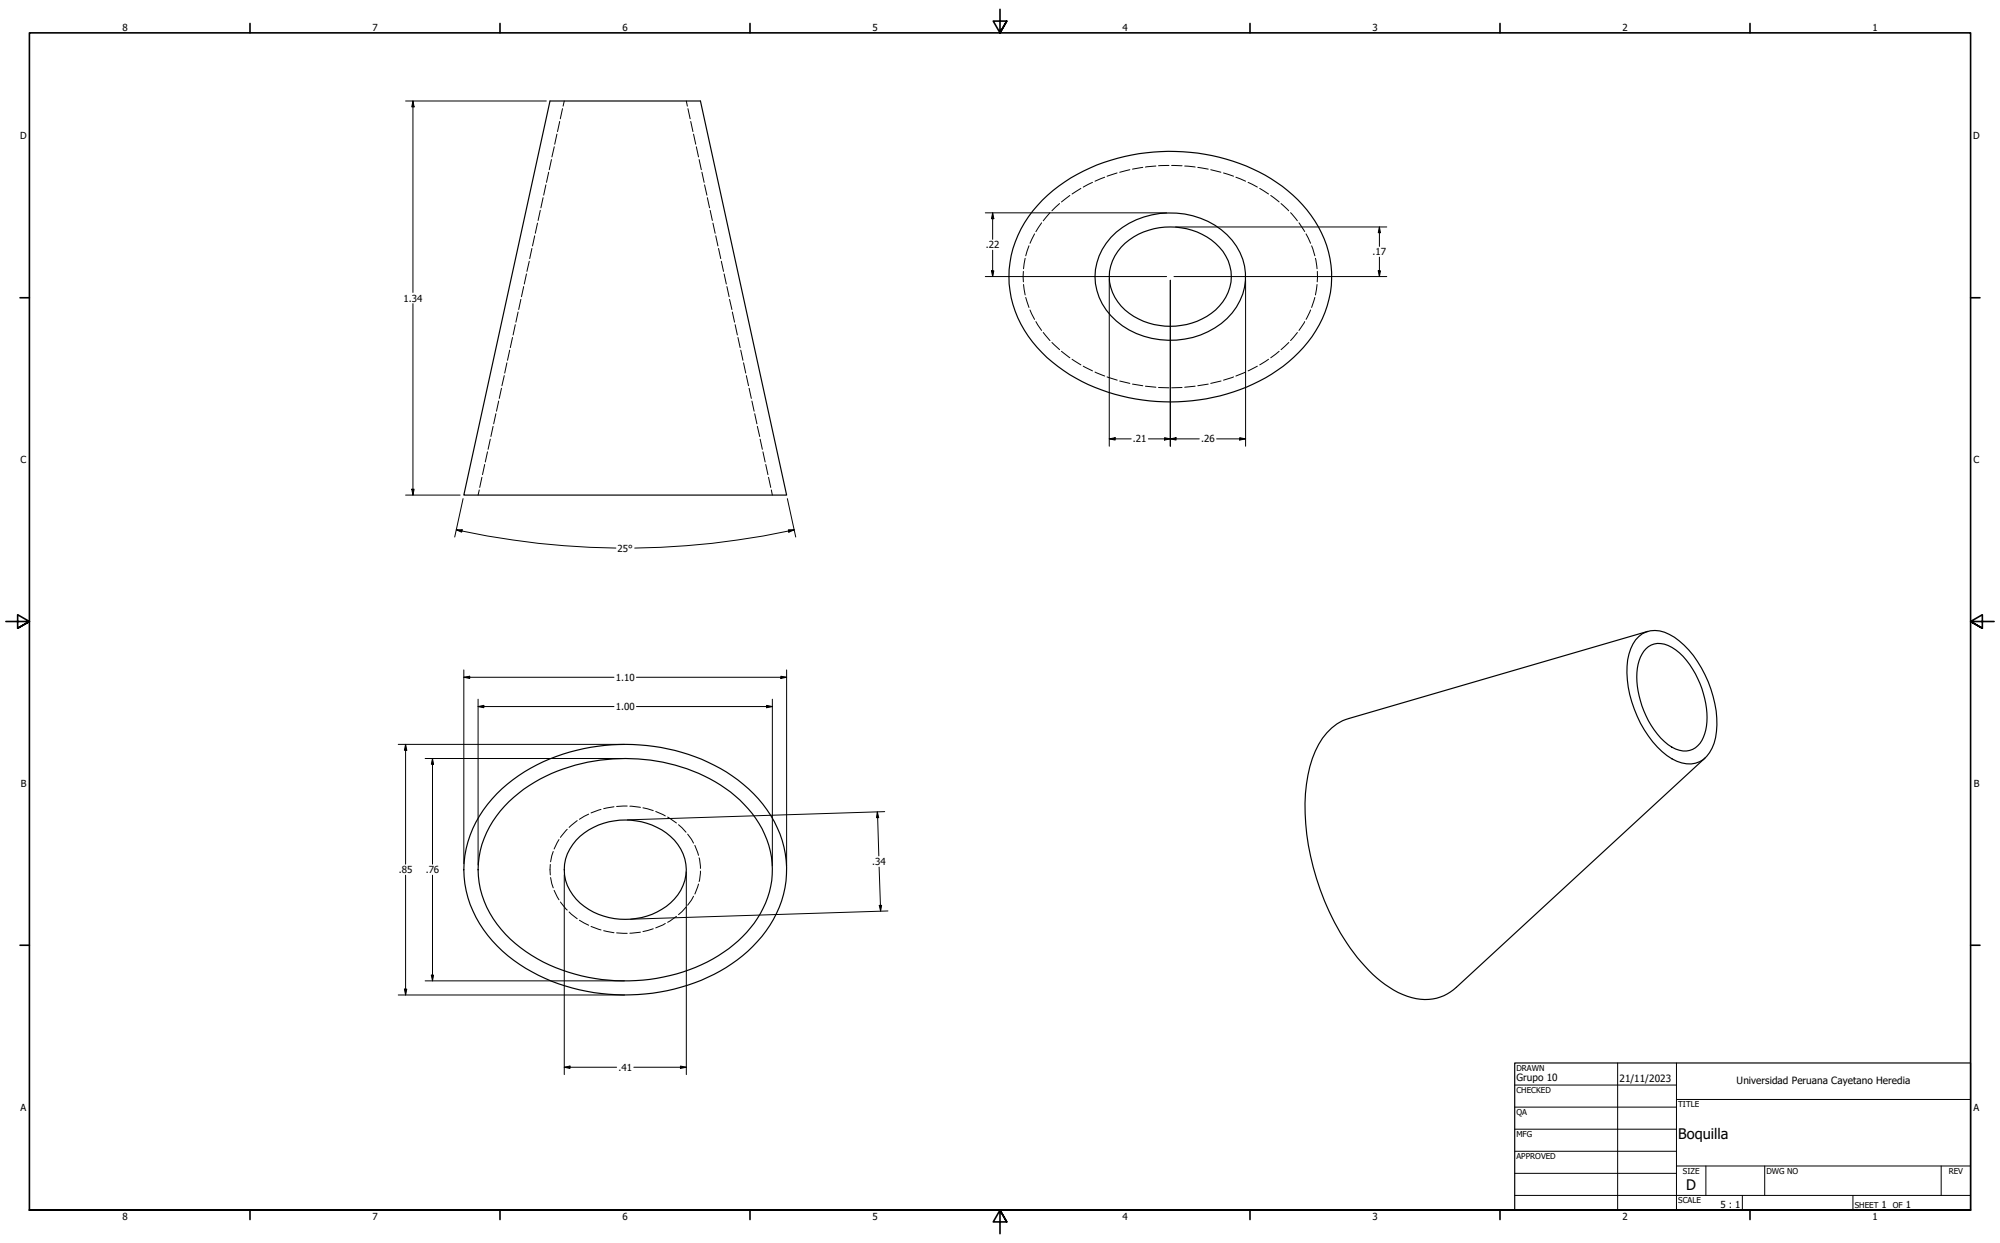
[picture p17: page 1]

DRAWN Grupo 10 | 21/11/2023 | Universidad Peruana Cayetano Heredia

CHECKED

MFG

APPROVED

SIZE D | DWG NO | REV

SCALE 5 : 1 | | SHEET 1 OF 1

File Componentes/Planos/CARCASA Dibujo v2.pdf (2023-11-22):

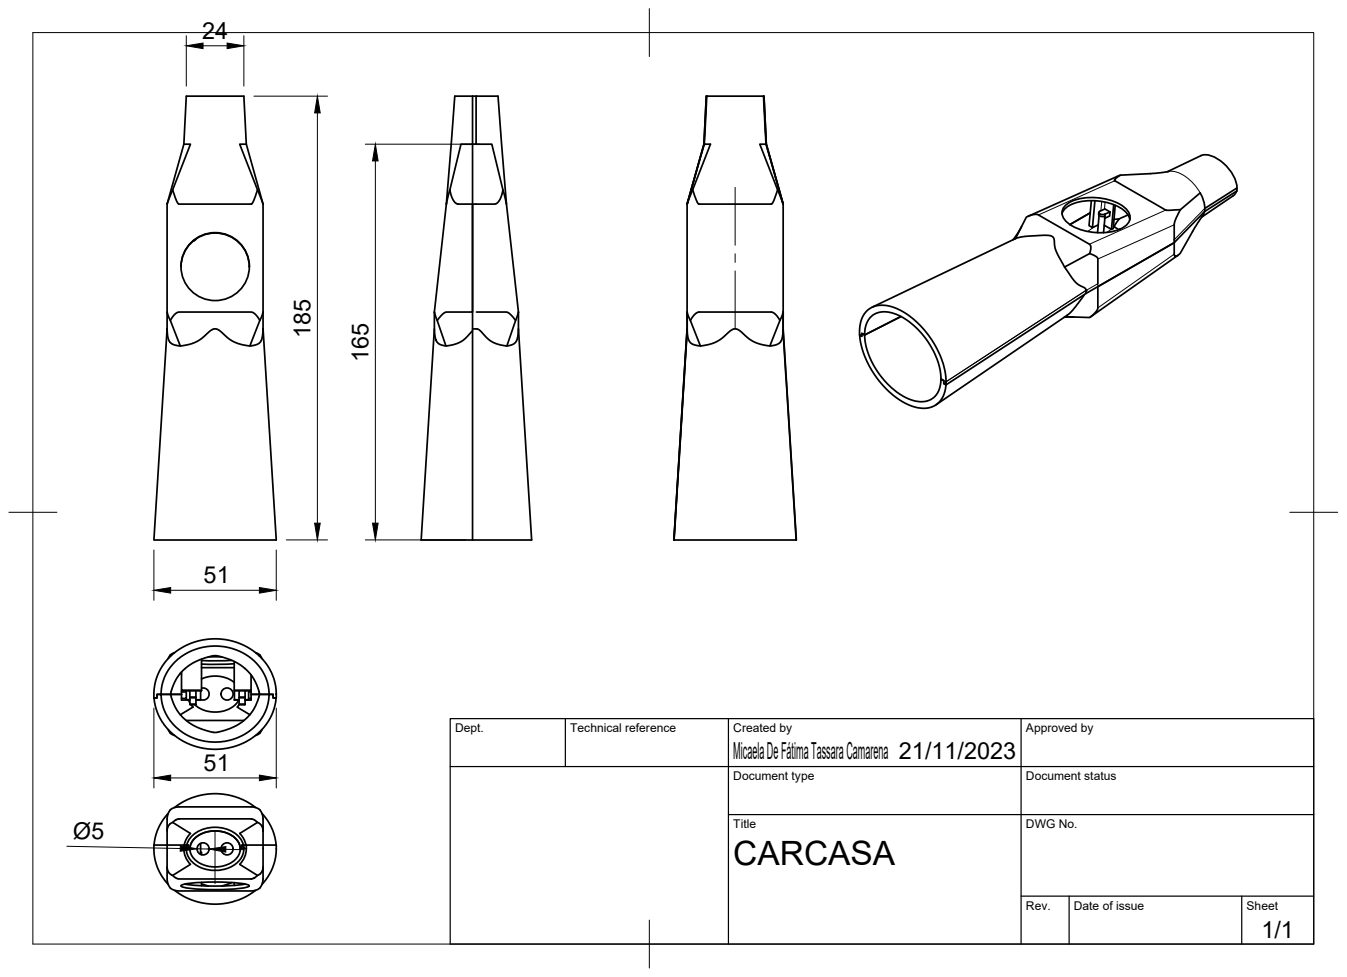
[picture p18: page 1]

Micaela De Fátima Tassara Camarena 185

Dept. | Technical reference | Created by 21/11/2023 | Approved by

Document type | Document status

Title CARCASA | DWG No.

Rev. | Date of issue | Sheet 1/1

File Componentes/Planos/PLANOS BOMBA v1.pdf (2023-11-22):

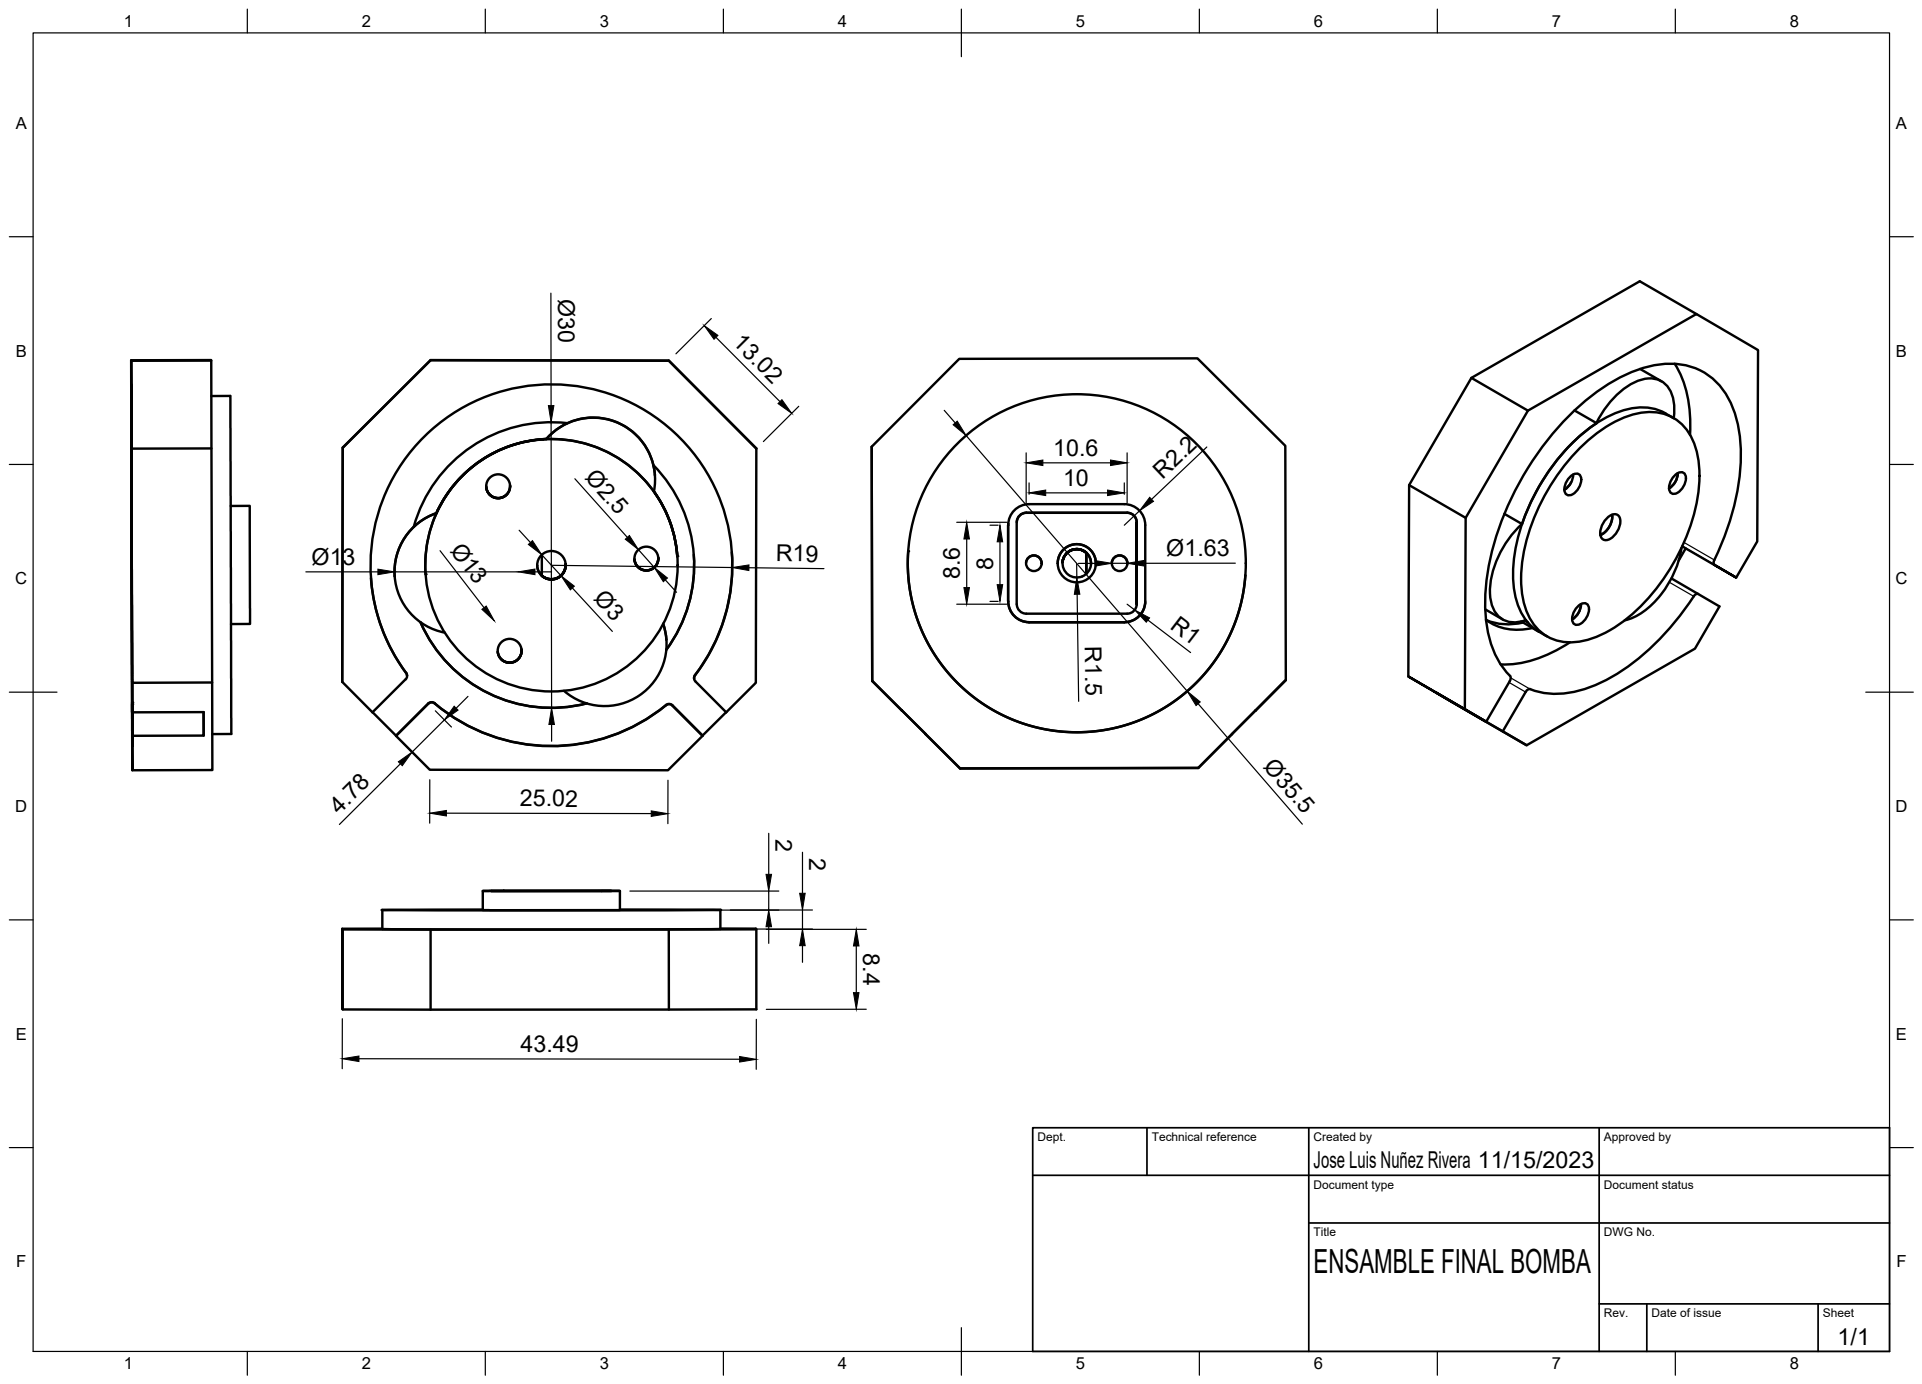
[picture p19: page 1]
Title; DWG No.; Rev.; Date of issue; Sheet

Dept. | Technical reference | Created by Jose Luis Nuñez Rivera 11/15/2023 | Approved by

Document type | Document status

ENSAMBLE FINAL BOMBA

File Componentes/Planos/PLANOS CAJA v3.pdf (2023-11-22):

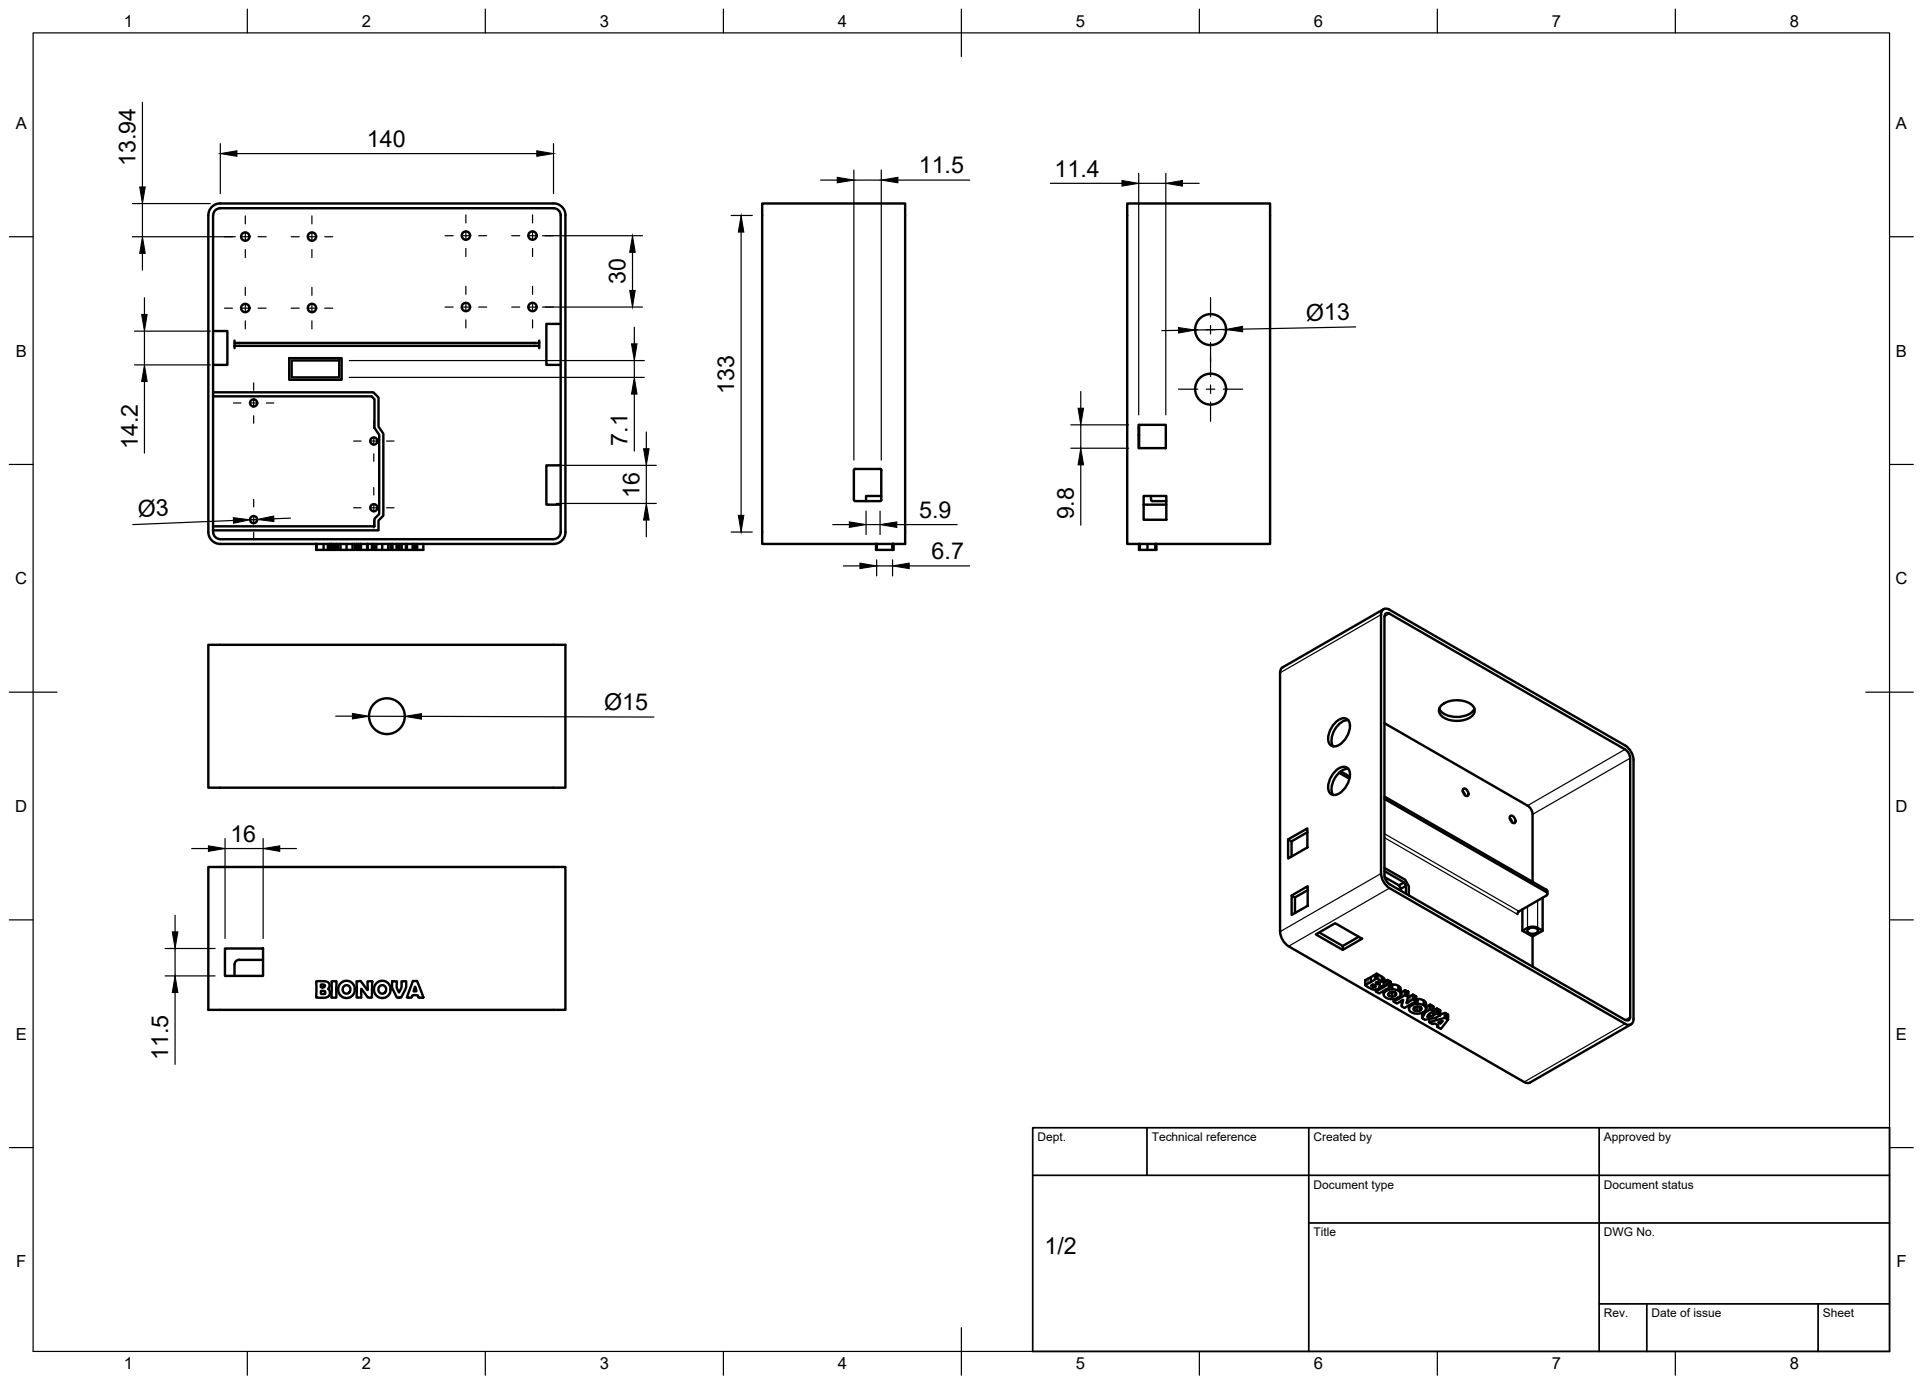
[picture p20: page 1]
Title; DWG No.; Rev.; Date of issue; Sheet

Dept. | Technical reference | Created by | Approved by

Document type | Document status

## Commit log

2025-06-06 Rename OPI - Ficha de detalles de la invención.pdf to OPI - Ficha de detalles de la invención
2025-06-06 Add files via upload
    Ficha de detalles de invención del proyecto realizado en Fundamentos de Biodiseño
2025-06-06 Delete Documentacion/OPI - Ficha de detalles de la invención
    Copy of
